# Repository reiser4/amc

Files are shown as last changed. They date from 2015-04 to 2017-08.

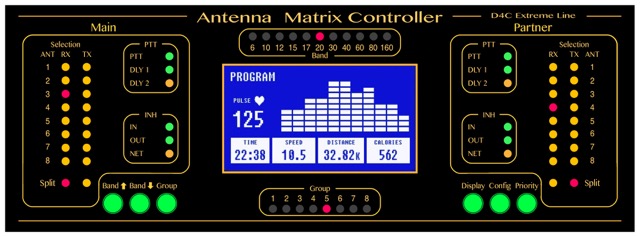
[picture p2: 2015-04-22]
webroot/front.jpg

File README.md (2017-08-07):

# amc

Software utilizzato su Windows:

 Python 3.5.0
 https://www.python.org/ftp/python/3.5.0/python-3.5.0-amd64-webinstall.exe

 PyQt5 5.5
 http://sourceforge.net/projects/pyqt/files/PyQt5/PyQt-5.5/PyQt5-5.5-gpl-Py3.4-Qt5.5.0-x64.exe

 py2exe 0.9.2.0
 https://pypi.python.org/packages/any/p/py2exe/py2exe-0.9.2.0.win-amd64.exe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

Per compilare per windows:

 python setup.py py2exe --includes sip

# funzionamento

il software AMC gira su beaglebone black. E` costituito da diversi componenti che interagiscono tra loro solamente tramite lettura e scrittura (atomica) di files in /tmp.

/tmp/band.txt
	contiene la banda in uso. puo` essere: 160, 80, 60, 40, 30, 20, 17, 15, 12, 10, 6

/tmp/relay.txt
	descrive i rele` attivi con la combinazione attuale di preset.
	esempio: 100000000000000000000000
	nella nostra implementazione usiamo i primi otto bits

/tmp/presetA.txt e /tmp/presetB.txt
	descrivono la combinazione da tastiera scelta dall'utente
	la pressione dei tasti provoca la variazione della combinazione
	esempio:
		TX: 01100000
		RX: 10010000

/tmp/presetTXTA.txt e /tmp/presetTXTB.txt
	contiene la lista testuale di preset attivi (per essere stampato sul display)
	senza spazi, separati da virgola, poi punto e virgola tra Rx e Tx
	esempio:
		Europa,Asia,America;Asia

/tmp/tx.txt
	contiene la lista di radio che stanno trasmettendo in quel momento
	esempio:
		A
		oppure
		B
		oppure 
		(file vuoto)

/root/amc/config.json
	contiene la configurazione con cui vengono determinate le varie combinazioni di relay da accendere.
	vedi file di esempio

# componenti software

MAIN:
	si occupa di prendere le decisioni riguardo i preset e relay da attivare.
	LEGGE: /root/amc/config.json /tmp/tx.txt /tmp/presetA.txt /tmp/presetB.txt /tmp/band.txt
	SCRIVE: /tmp/relay.txt /tmp/presetTXTA.txt /tmp/presetTXTB.txt

IOLOOP:
	ascolta il GPIO hardware per determinare la banda e la radio trasmittente.
	SCRIVE: /tmp/band.txt /tmp/tx.txt

DISPLAY:
	si occupa di mantenere il display aggiornato con lo stato attuale.
	LEGGE: /tmp/tx.txt /tmp/band.txt /tmp/presetTXTA.txt /tmp/presetTXTB.txt

KEYBOARD:
	rimane in ascolto di input da tastiera e fa i toggle dei bits dei preset
	LEGGE: /tmp/presetA.txt /tmp/presetB.txt
	SCRIVE: /tmp/presetA.txt /tmp/presetB.txt

SERIAL:
	svolge due funzioni: riporta periodicamente sulla seriale lo stato attuale per poter essere visualizzato sul pc,
	ed interagisce col pc per inviare e ricevere la configurazione.
	LEGGE: /tmp/presetA.txt /tmp/presetB.txt /tmp/tx.txt /tmp/band.txt /tmp/presetTXTA.txt /tmp/presetTXTB.txt /root/amc/config.json
	SCRIVE: /root/amc/config.json

RELAY:
	scrive su GPIO le uscite relay
	LEGGE: /tmp/relay.txt

CHECK:
	verifica che tutti i processi siano in esecuzione ed avvia eventuali processi fermi.

===================================

Requisiti software

# apt-get install git
# pip install Pillow

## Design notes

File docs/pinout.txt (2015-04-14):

PEDINATURA

P9_11 port B FTDI 232 tx
P9_12 LED shift register DATA OUT
P9_13 port B ftdi 232 rx
P9_14 led shift reg sck
P9_15 inh in A
P9_16 led shirf reg rck
P9_17 inh in B
P9_18 BCD A OUT

P9_22 BCD B OUT
P9_23 relay shift reg data out
P9_24 port A ftdi 232 tx
P9_25 relay shift reg sck
P9_26 port A ftdi 232 rx
P9_27 relay shift reg rck
P9_28 bcd c out
P9_29 inh out a
P9_30 bcd d out
P9_31 int out b
P9_33 icom voltage in
P9_41 button 3 in
P9_42 button 4 in

P8_07 ptt a out
P8_08 ptt a in
P8_09 ptt a out delay 1
P8_10 ptt b in
P8_11 ptt a out delay 2
P8_12 bcd a in
P8_13 ptt b out
P8_14 bcd b in
P8_15 ptt b out delay 1
P8_16 bcd c in
P8_17 ptt b out delay 2
P8_18 bcd d in
P8_19 button 1 in

P8_26 button 2 in

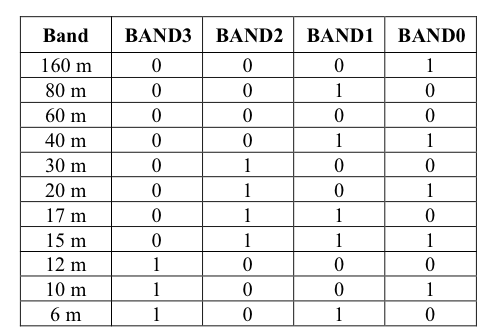
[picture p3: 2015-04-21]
docs/bcd.png

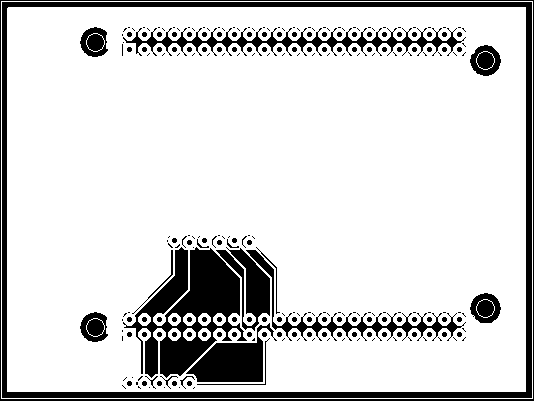
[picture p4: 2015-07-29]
eagle_file/Modulo0.png

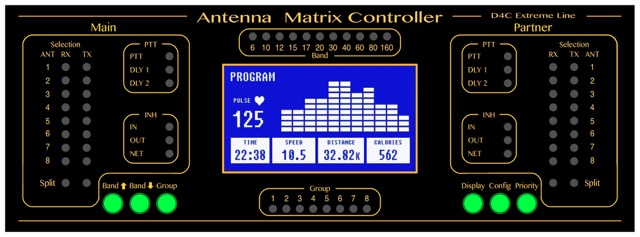
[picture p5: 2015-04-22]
webroot/front-off.jpg

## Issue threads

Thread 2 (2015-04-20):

lettura banda BCD

reiser4, 2015-04-20:
hardware: interfacciare gli ingressi BCD (5v) agli ingressi del micro (3.3v) tramite partitori resistivi

software: leggere i quattro piedini per determinare la banda

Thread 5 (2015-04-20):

gestione tastiere

reiser4, 2015-04-20:
software: creare un modulo che mantenga una memoria di tipo "toggle" dei tasti premuti.
gestire l'evento di pressione del tasto.
in secondo momento: gestire accensione e spegnimento dei led su barra x-keys

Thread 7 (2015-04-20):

driver i2c expander

reiser4, 2015-04-20:
creare un driver python per gestire ad alta velocita` l'i2c expander.
serve in sola scrittura, quindi chiamate tipo: setPin(5, HIGH)

Closed 2015-07-23.

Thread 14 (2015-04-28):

libreria grafica

reiser4, 2015-04-28:
funzione per disegnare una riga orizzontale o verticale
funzione per fare il testo a dimensione doppia

giulioribe, 2015-05-08:
Uso delle libreria Pillow: http://pillow.readthedocs.org/

Closed 2015-05-08.

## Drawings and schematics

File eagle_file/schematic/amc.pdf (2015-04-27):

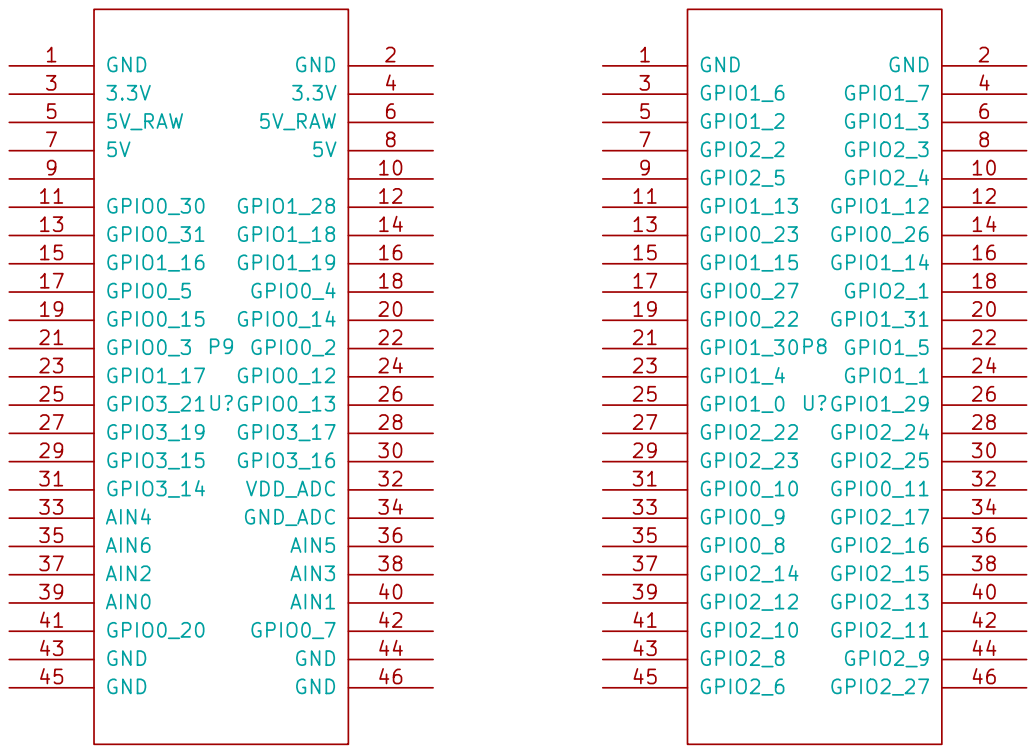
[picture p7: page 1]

Id: 1/1 Title: File: amc.sch Sheet: /

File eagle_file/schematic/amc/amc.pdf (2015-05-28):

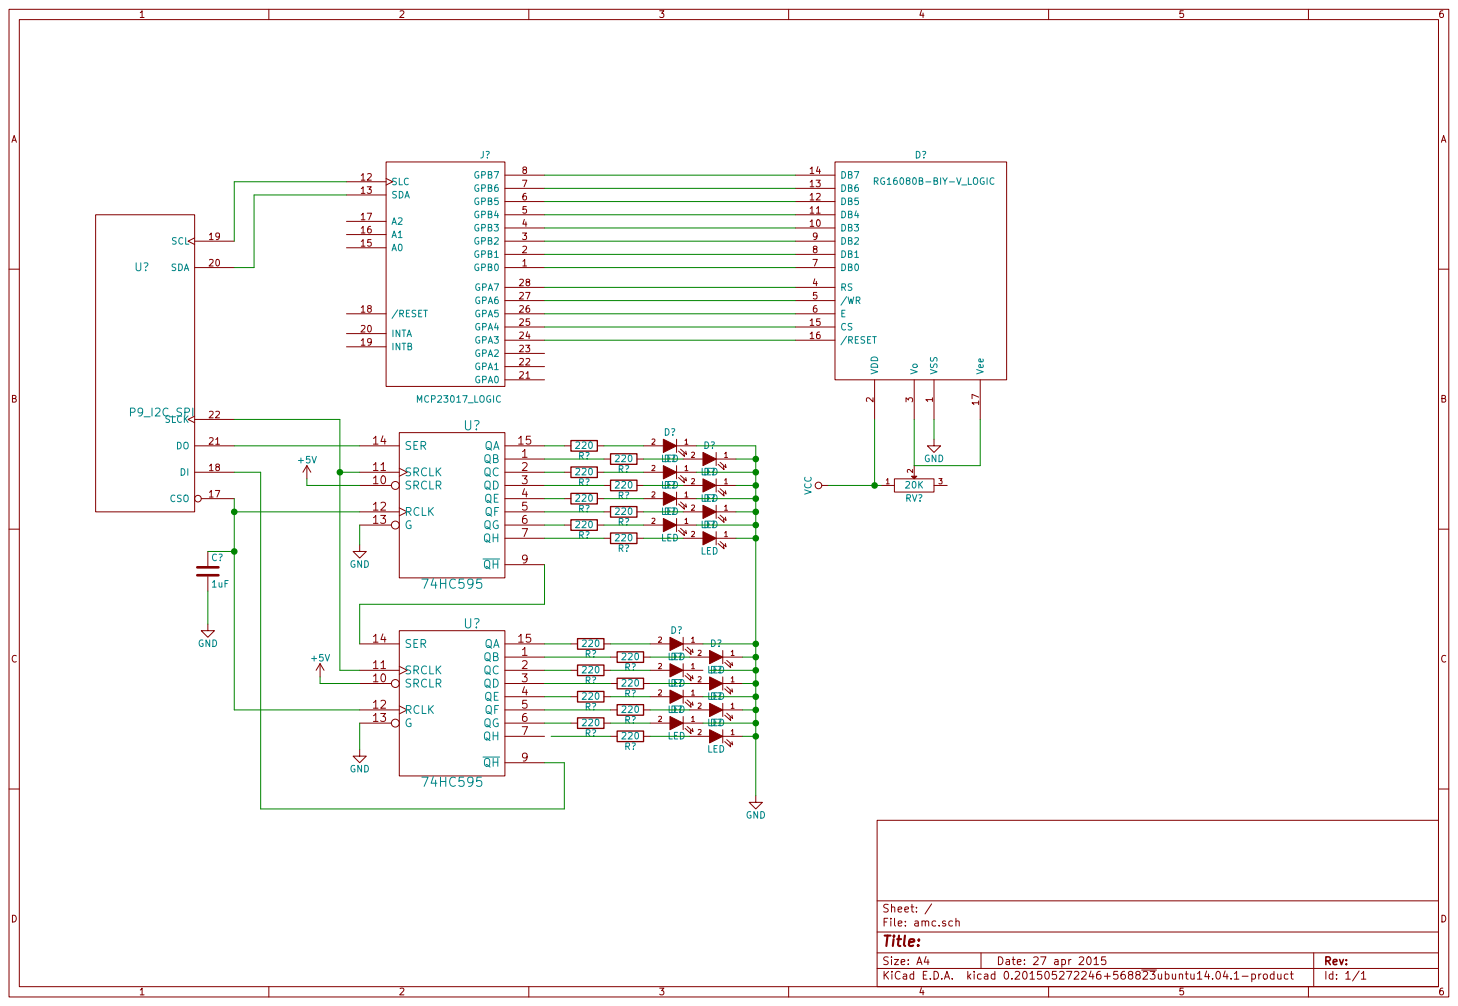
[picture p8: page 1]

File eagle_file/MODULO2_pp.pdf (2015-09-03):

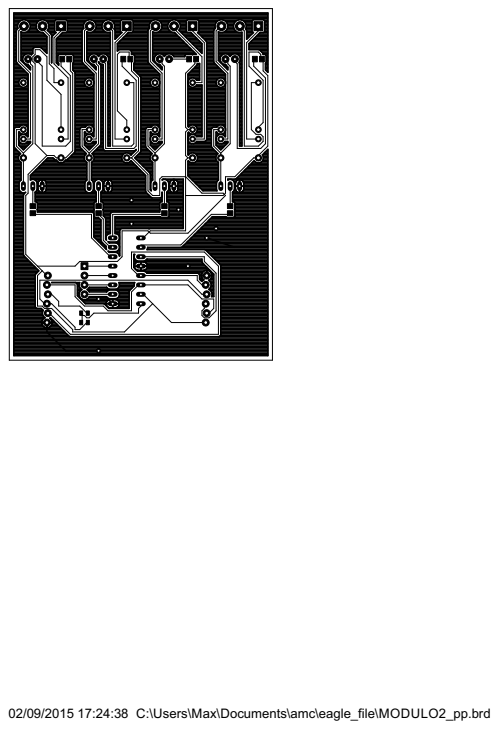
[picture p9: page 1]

02/09/2015 17:24:38 C:\Users\Max\Documents\amc\eagle_file\MODULO2_pp.brd

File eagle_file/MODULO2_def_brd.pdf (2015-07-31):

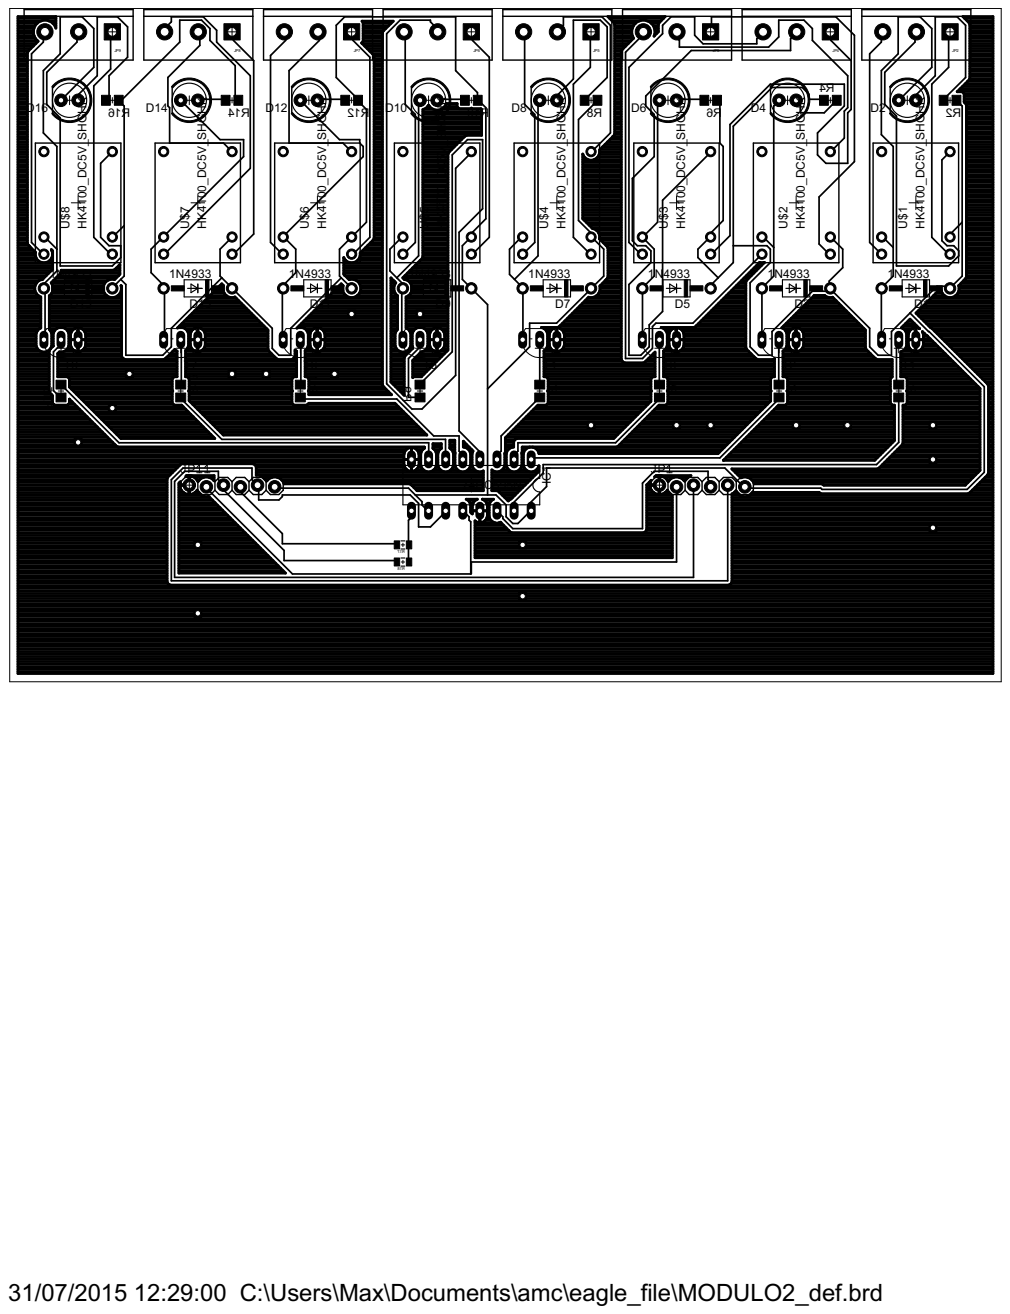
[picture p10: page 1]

31/07/2015 12:29:00 C:\Users\Max\Documents\amc\eagle_file\MODULO2_def.brd

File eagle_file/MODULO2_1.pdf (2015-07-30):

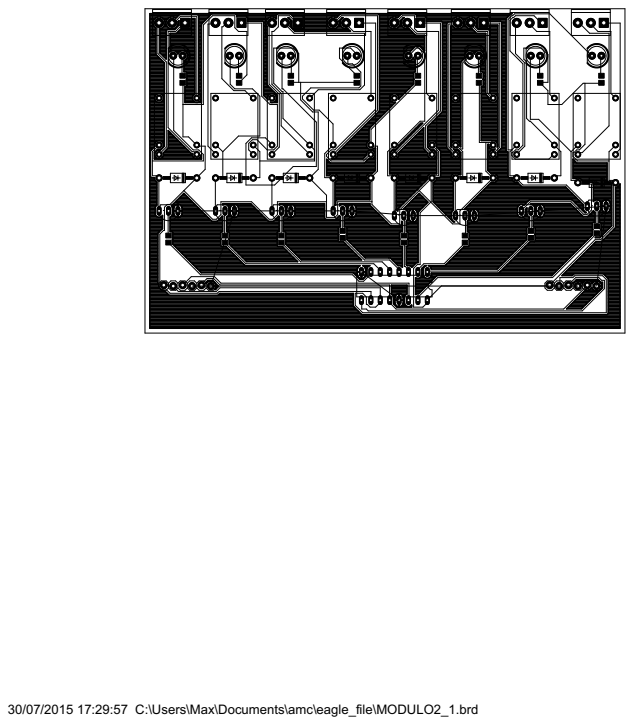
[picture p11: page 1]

30/07/2015 17:29:57 C:\Users\Max\Documents\amc\eagle_file\MODULO2_1.brd

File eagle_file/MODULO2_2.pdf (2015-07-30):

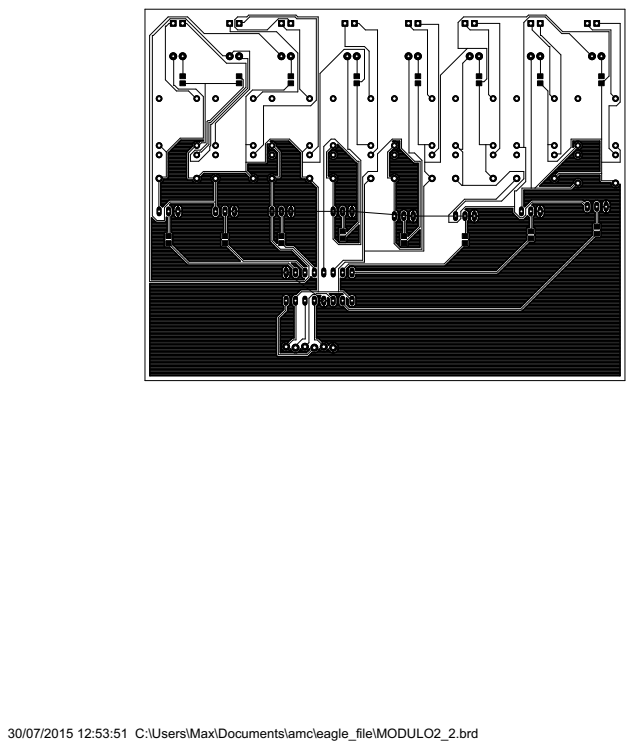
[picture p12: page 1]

30/07/2015 12:53:51 C:\Users\Max\Documents\amc\eagle_file\MODULO2_2.brd

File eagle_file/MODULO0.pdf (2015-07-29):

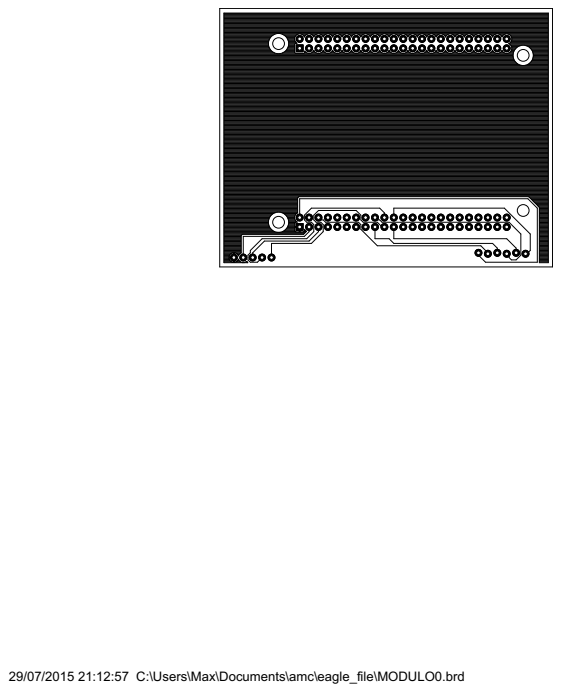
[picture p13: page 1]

29/07/2015 21:12:57 C:\Users\Max\Documents\amc\eagle_file\MODULO0.brd

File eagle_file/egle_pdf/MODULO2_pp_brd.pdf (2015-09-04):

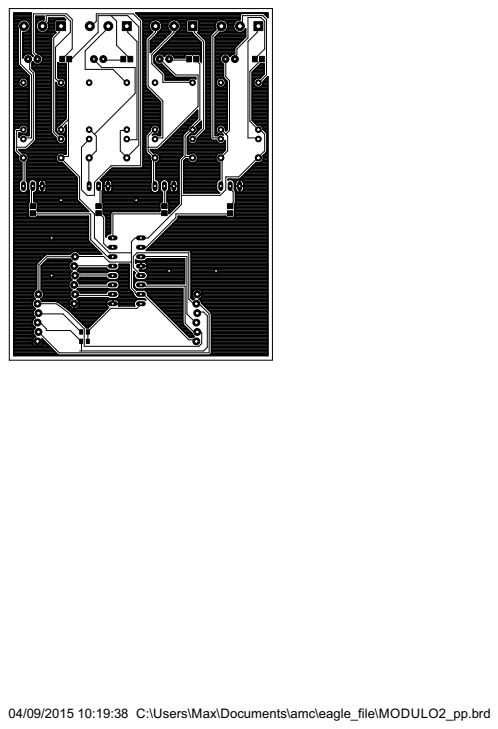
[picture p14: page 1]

04/09/2015 10:19:38 C:\Users\Max\Documents\amc\eagle_file\MODULO2_pp.brd

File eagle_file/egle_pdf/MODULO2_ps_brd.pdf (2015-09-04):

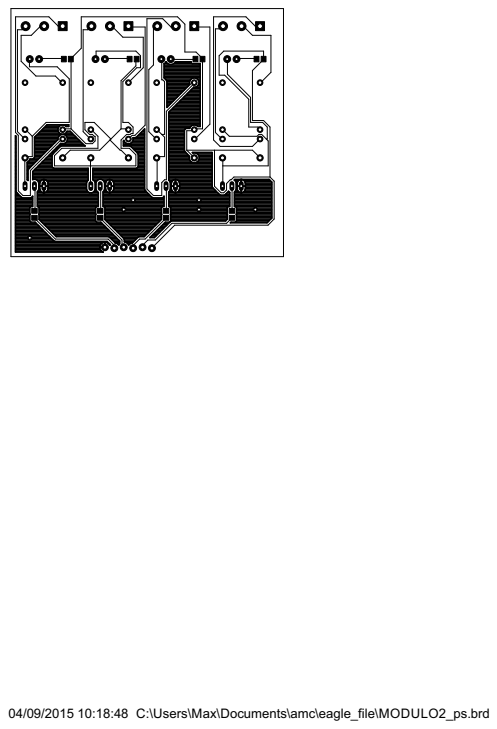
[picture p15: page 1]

04/09/2015 10:18:48 C:\Users\Max\Documents\amc\eagle_file\MODULO2_ps.brd

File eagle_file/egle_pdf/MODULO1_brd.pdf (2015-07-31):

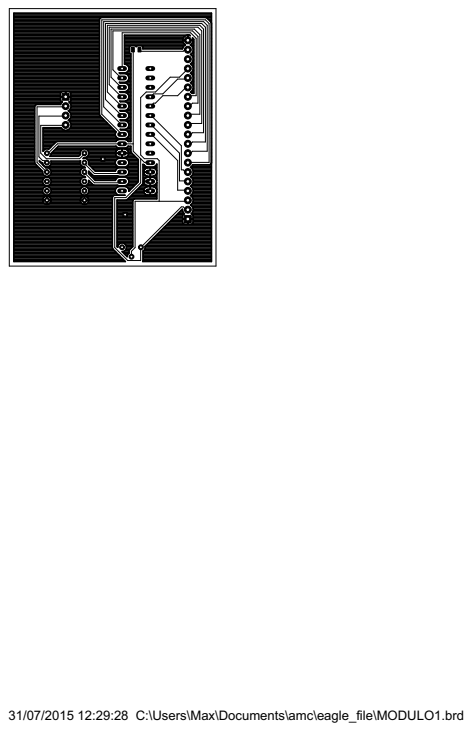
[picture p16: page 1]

31/07/2015 12:29:28 C:\Users\Max\Documents\amc\eagle_file\MODULO1.brd

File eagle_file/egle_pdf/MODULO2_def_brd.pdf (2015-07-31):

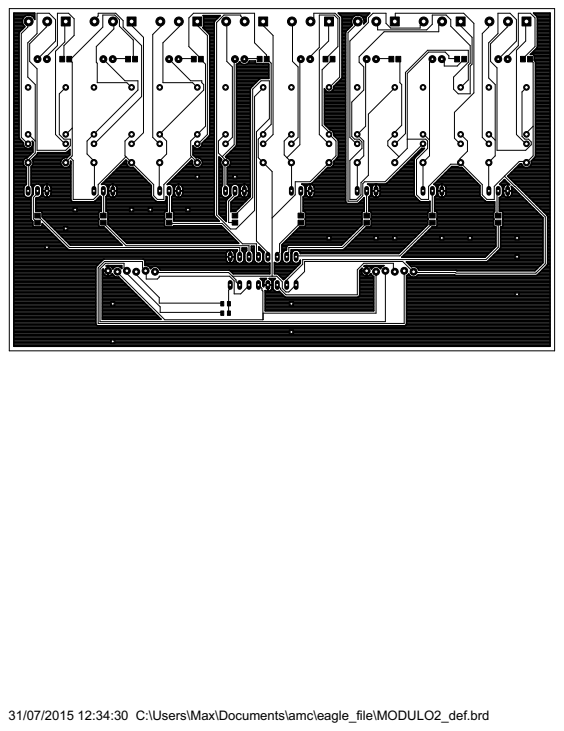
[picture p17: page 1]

31/07/2015 12:34:30 C:\Users\Max\Documents\amc\eagle_file\MODULO2_def.brd

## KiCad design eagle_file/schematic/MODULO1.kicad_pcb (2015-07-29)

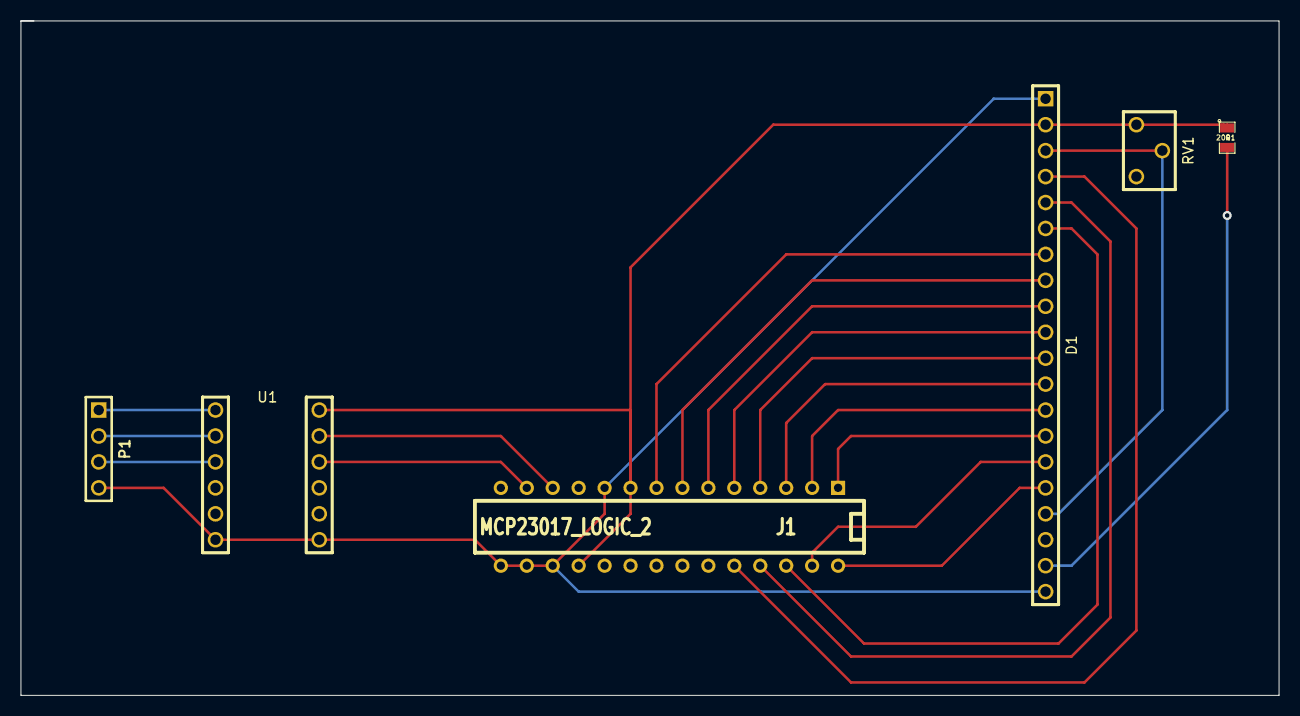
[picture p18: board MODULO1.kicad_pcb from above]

Board: 2 copper layers, 123.2 x 66.0 mm, 6 parts (0 on the bottom side), 22 nets.

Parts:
D1: RG16080B-BIY-V_LOGIC_2; ZZPIN20
J1: MCP23017_LOGIC_2; DIP-28__300
P1: CONN_4; PIN_ARRAY_4x1
R1: 200; SM0805
RV1: POT; ZZTRIMMER
U1: L_CONVERTER

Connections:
/SCL: P1.2, U1.2
/SDA: P1.3, U1.3
GND: D1.1, D1.20, J1.10, J1.15, J1.16, J1.17, P1.4, U1.6, U1.7
unnamed: J1.13, U1.10
unnamed: D1.12, J1.3
unnamed: D1.13, J1.2
unnamed: D1.11, J1.4
unnamed: D1.10, J1.5
unnamed: D1.9, J1.6
unnamed: D1.8, J1.7
unnamed: D1.7, J1.8
unnamed: D1.5, J1.25
unnamed: D1.2, J1.9, J1.18, R1.1, RV1.1, U1.12
unnamed: D1.4, J1.24
unnamed: D1.6, J1.26
unnamed: D1.15, J1.27
unnamed: D1.16, J1.28
unnamed: D1.3, D1.17, RV1.2
unnamed: J1.12, U1.11
unnamed: D1.19, R1.2
unnamed: D1.14, J1.1
VCC: P1.1, U1.1

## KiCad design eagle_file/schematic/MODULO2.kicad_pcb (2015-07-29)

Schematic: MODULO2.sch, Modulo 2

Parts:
D1, D2, D3, D4, D5, D6, D7, D8: LED
P1: CONN_6
R1, R2, R3, R4, R5, R6, R7, R8: R
U1: 74HC595

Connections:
/SCLK: P1.2, U1.11 (SRCLK)
GND: D1.2 (A), D2.2 (A), D3.2 (A), D4.2 (A), D5.2 (A), D6.2 (A), D7.2 (A), D8.2 (A), P1.6, U1.8 (GND), U1.13 (G)
unnamed: R4.1, U1.6 (QG)
unnamed: D7.1 (K), R7.2
unnamed: R7.1, U1.5 (QF)
unnamed: D3.1 (K), R3.2
unnamed: R3.1, U1.4 (QE)
unnamed: D4.1 (K), R4.2
unnamed: D6.1 (K), R6.2
unnamed: R6.1, U1.3 (QD)
unnamed: D2.1 (K), R2.2
unnamed: R2.1, U1.2 (QC)
unnamed: D5.1 (K), R5.2
unnamed: R5.1, U1.1 (QB)
unnamed: D8.1 (K), R8.2
unnamed: R8.1, U1.7 (QH)
unnamed: R1.1, U1.15 (QA)
unnamed: P1.3, U1.14 (SER)
unnamed: P1.5, U1.12 (RCLK)
unnamed: D1.1 (K), R1.2
unnamed: P1.4, U1.9 (~QH)
VCC: P1.1, U1.10 (SRCLR), U1.16 (VCC)

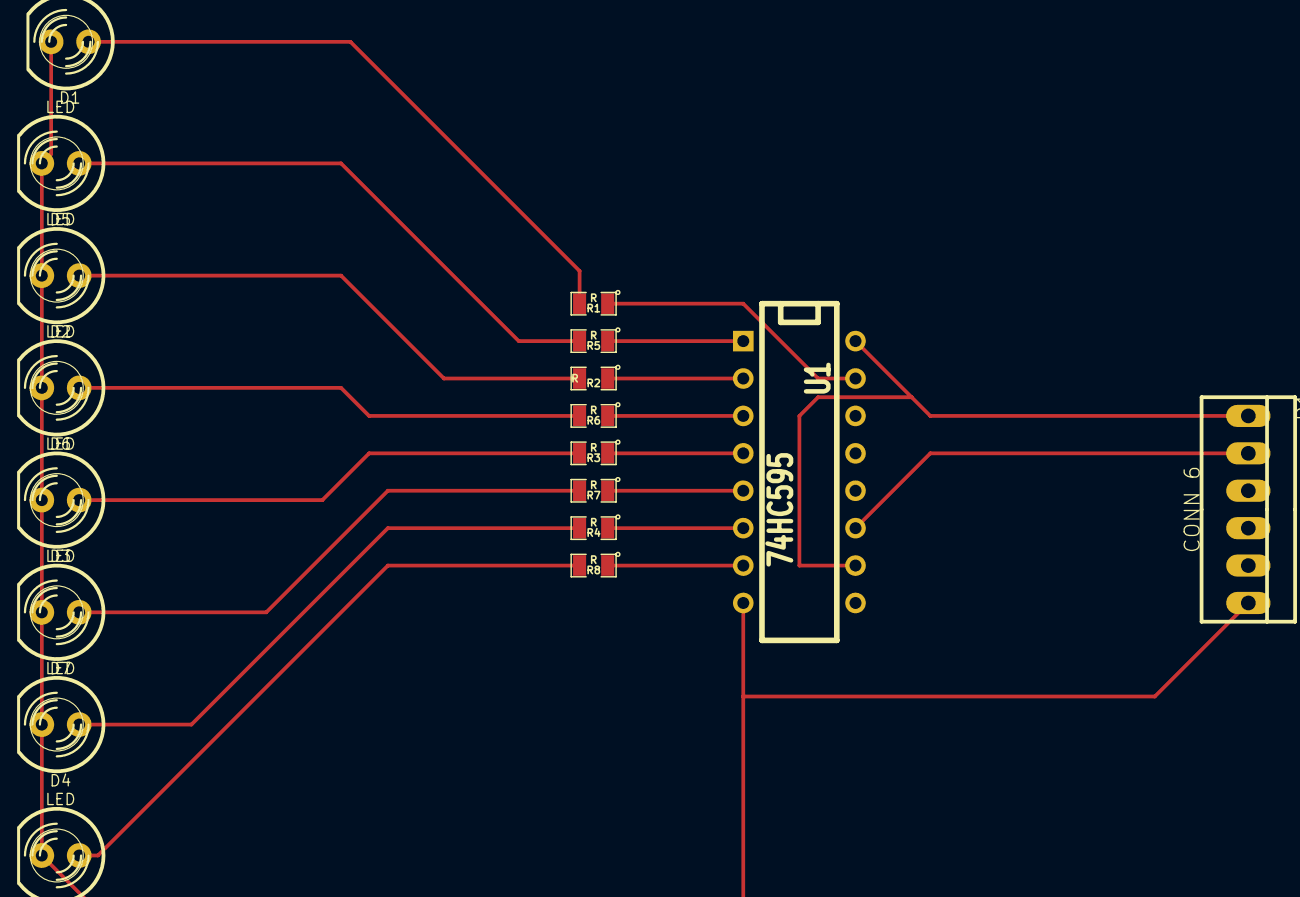
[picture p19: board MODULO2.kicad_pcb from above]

Board: 2 copper layers, 18 parts (0 on the bottom side), 22 nets.

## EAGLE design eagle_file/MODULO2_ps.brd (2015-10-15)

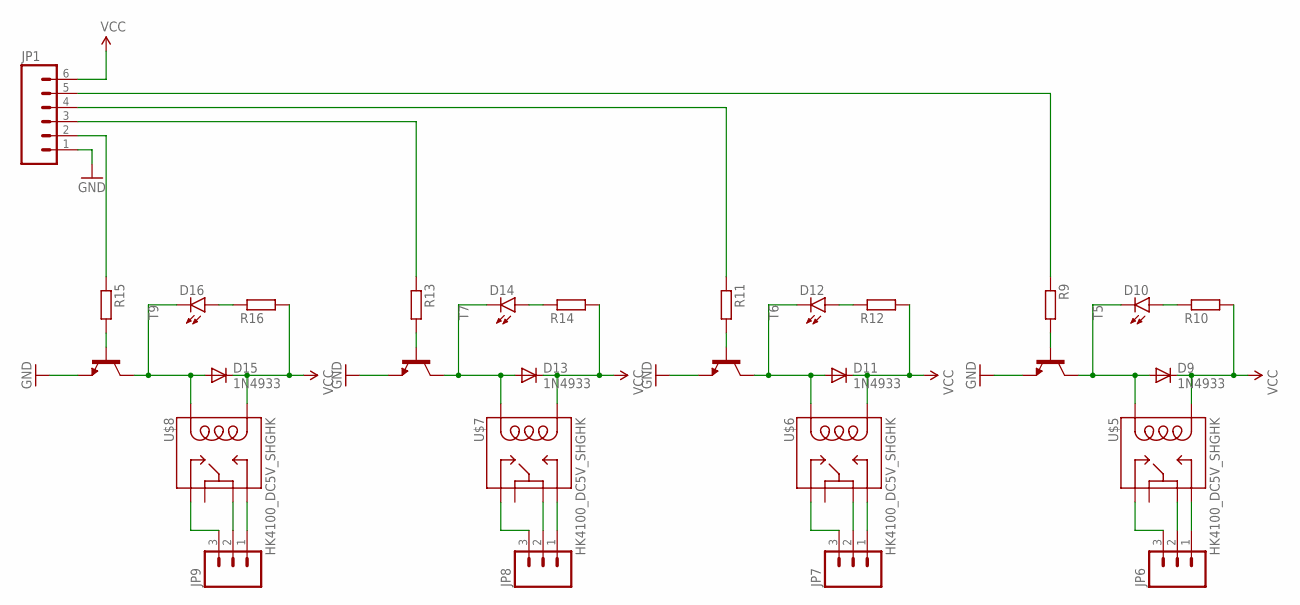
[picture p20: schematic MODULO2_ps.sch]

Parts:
D9, D11, D13, D15: 1N4933; DO41-10
D10, D12, D14, D16: LED5MM
JP1: M06SILK_FEMALE_PTH; 1X06
JP6, JP7, JP8, JP9: M03-SCREW-5MM; SCREWTERMINAL-5MM-3
R9, R10, R11, R12, R13, R14, R15, R16: R-EU_R0805; R0805
T5, T6, T7, T9: -NPN-TO92-EBC; TO92-EBC
U$5, U$6, U$7, U$8: HK4100_DC5V_SHGHK; HK4100

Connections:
GND: JP1.1, T5.E, T6.E, T7.E, T9.E
unnamed: D9.A, D10.K (C), T5.C, U$5.6 (2)
unnamed: D10.A, R10.1
unnamed: R9.2, T5.B
unnamed: D11.A, D12.K (C), T6.C, U$6.6 (2)
unnamed: D12.A, R12.1
unnamed: R11.2, T6.B
unnamed: D13.A, D14.K (C), T7.C, U$7.6 (2)
unnamed: D14.A, R14.1
unnamed: R13.2, T7.B
unnamed: D15.A, D16.K (C), T9.C, U$8.6 (2)
unnamed: D16.A, R16.1
unnamed: R15.2, T9.B
unnamed: JP1.4, R11.1
unnamed: JP1.5, R9.1
unnamed: JP1.3, R13.1
unnamed: JP1.2, R15.1
unnamed: JP6.1, U$5.8 (10)
unnamed: JP6.2, U$5.14 (6)
unnamed: JP6.3, U$5.7 (1)
unnamed: JP7.1, U$6.8 (10)
unnamed: JP7.2, U$6.14 (6)
unnamed: JP7.3, U$6.7 (1)
unnamed: JP8.1, U$7.8 (10)
unnamed: JP8.2, U$7.14 (6)
unnamed: JP8.3, U$7.7 (1)
unnamed: JP9.1, U$8.8 (10)
unnamed: JP9.2, U$8.14 (6)
unnamed: JP9.3, U$8.7 (1)
VCC: D9.C, D11.C, D13.C, D15.C, JP1.6, R10.2, R12.2, R14.2, R16.2, U$5.9, U$6.9, U$7.9, U$8.9

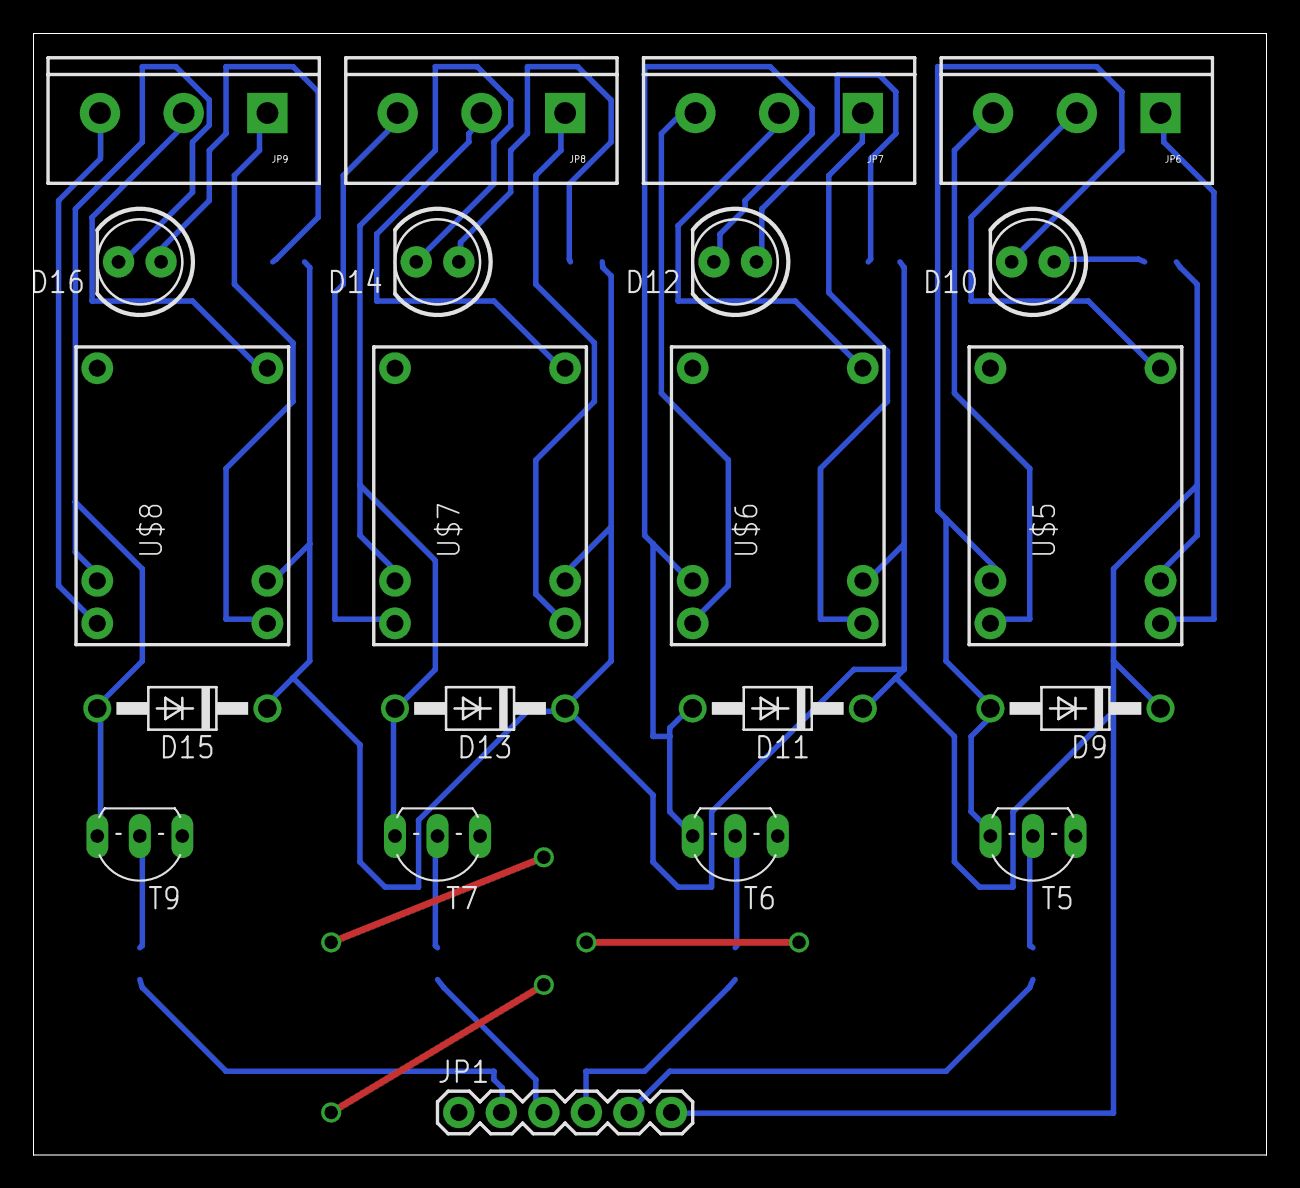
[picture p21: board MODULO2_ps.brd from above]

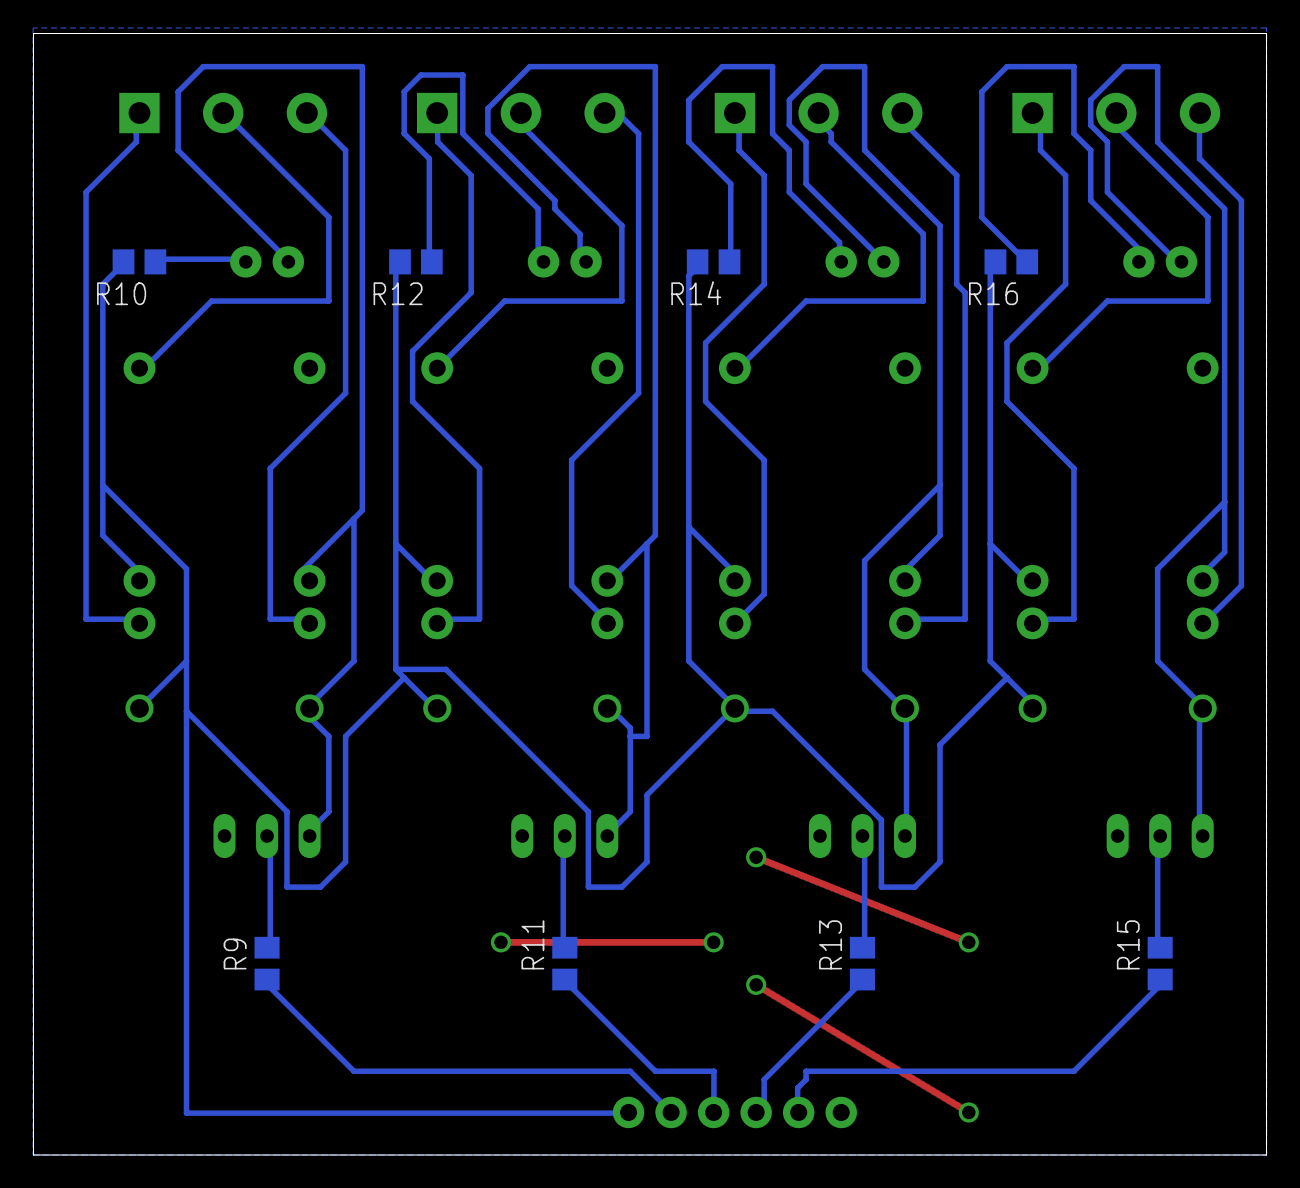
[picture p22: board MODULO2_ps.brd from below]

Board: 2 copper layers, 73.6 x 67.0 mm, 29 parts (8 on the bottom side), 30 nets.

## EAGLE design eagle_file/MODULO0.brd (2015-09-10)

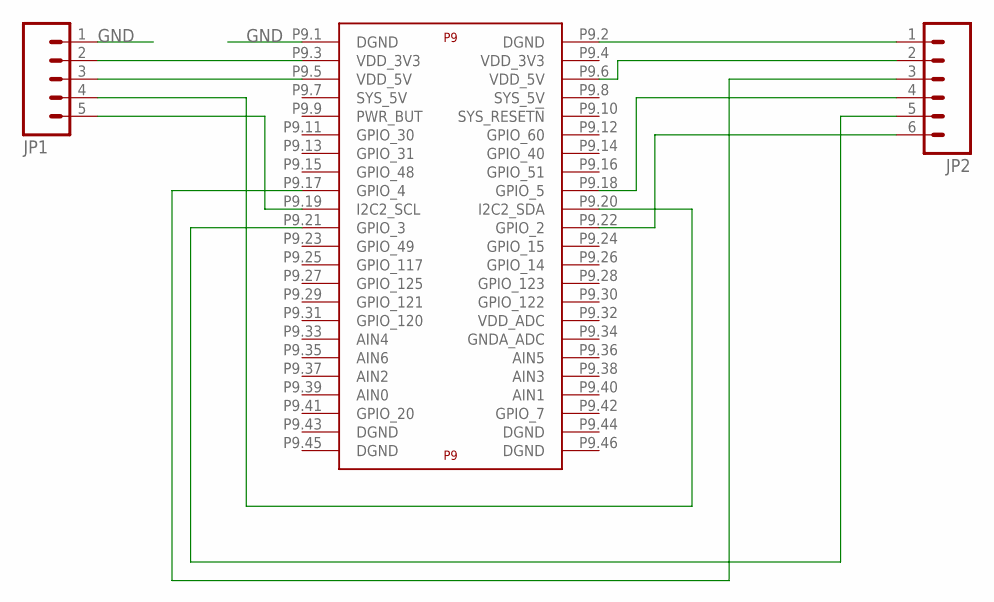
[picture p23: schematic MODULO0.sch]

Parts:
JP1: M05PTH; 1X05
JP2: M06SILK_FEMALE_PTH; 1X06
U$1: BEAGLE_BONE_BLACK_CAPE

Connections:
GND: JP1.1, U$1.P9.1 (DGND)
unnamed: JP1.2, U$1.P9.3 (VDD_3V3)
unnamed: JP1.3, U$1.P9.5 (VDD_5V)
unnamed: JP1.5, U$1.P9.19 (I2C2_SCL)
unnamed: JP1.4, U$1.P9.20 (I2C2_SDA)
unnamed: JP2.1, U$1.P9.2 (DGND)
unnamed: JP2.2, U$1.P9.6 (VDD_5V)
unnamed: JP2.3, U$1.P9.17 (GPIO_4)
unnamed: JP2.4, U$1.P9.18 (GPIO_5)
unnamed: JP2.6, U$1.P9.22 (GPIO_2)
unnamed: JP2.5, U$1.P9.21 (GPIO_3)

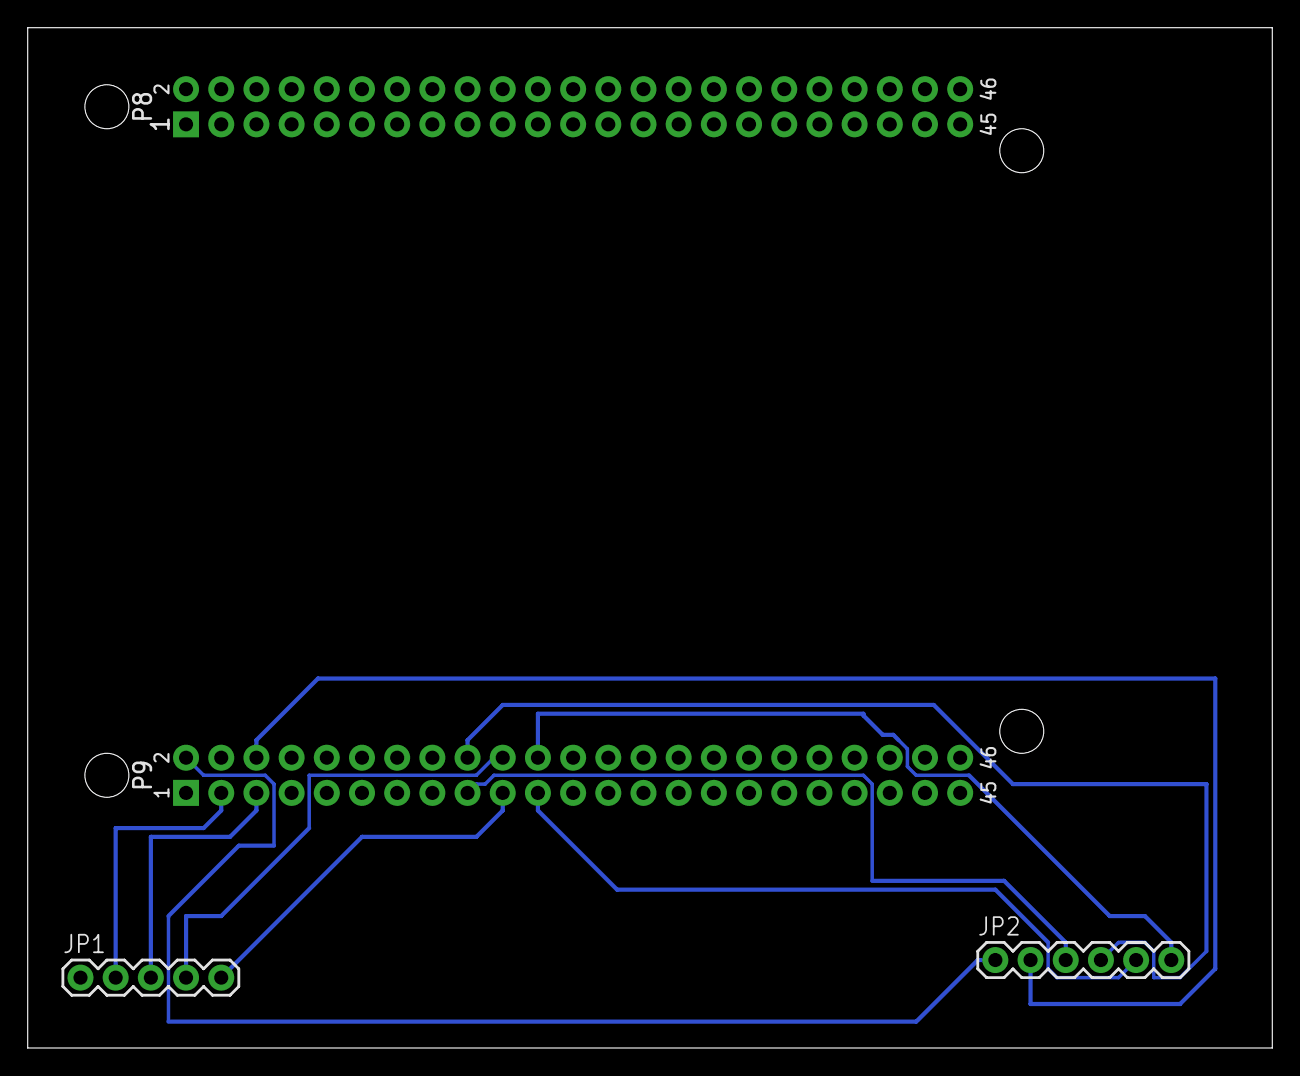
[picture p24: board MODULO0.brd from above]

Board: 2 copper layers, 89.8 x 73.7 mm, 3 parts (0 on the bottom side), 11 nets.

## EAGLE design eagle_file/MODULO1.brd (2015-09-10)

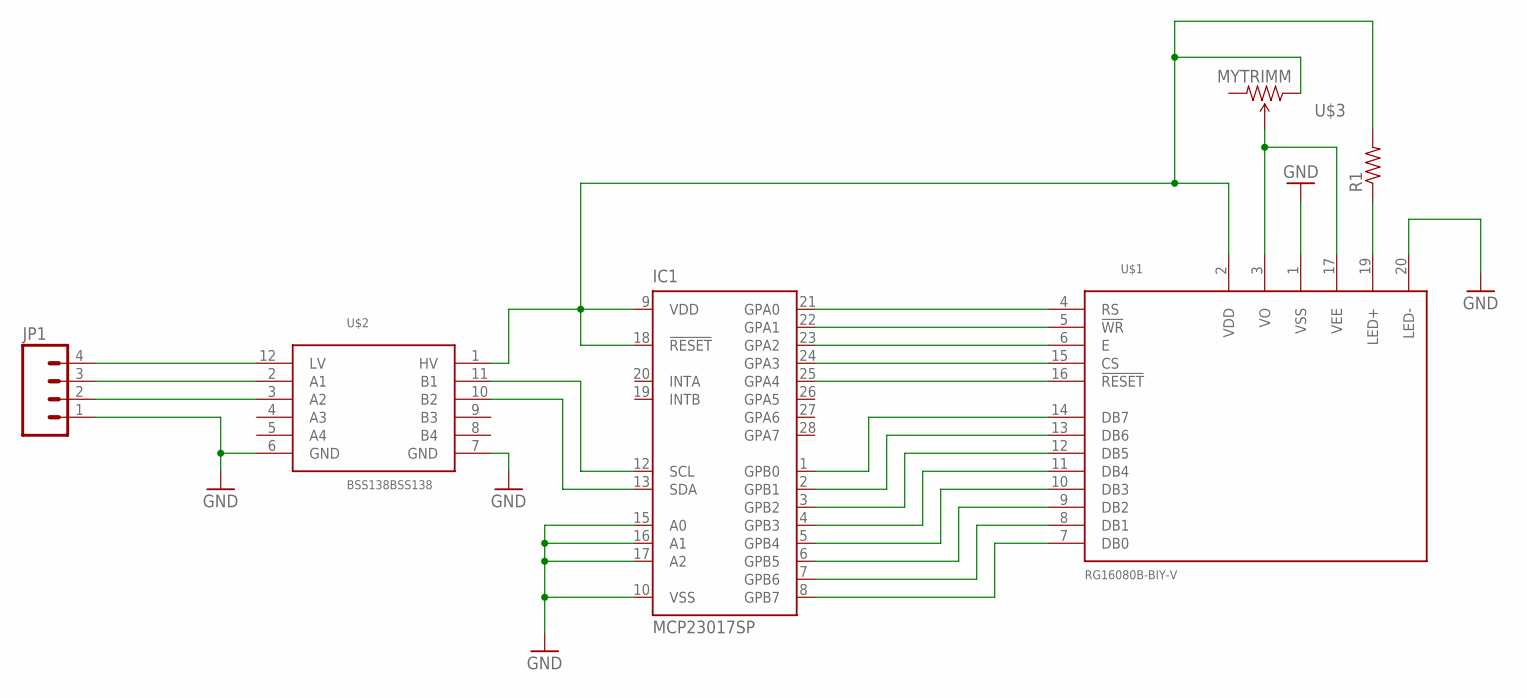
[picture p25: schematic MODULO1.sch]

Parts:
IC1: MCP23017SP; DIL28-3
JP1: M04PTH; 1X04
R1: RESISTOR0805-RES; 0805
U$1: RG16080B-BIY-V; 1X20
U$2: BSS138BSS138; BSS138
U$3: MYTRIMM

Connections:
GND: IC1.10 (VSS), IC1.15 (A0), IC1.16 (A1), IC1.17 (A2), JP1.1, U$1.1 (VSS), U$1.20 (LED-), U$2.6 (GND), U$2.7 (GND)
unnamed: IC1.21 (GPA0), U$1.4 (RS)
unnamed: IC1.22 (GPA1), U$1.5 (!WR)
unnamed: IC1.23 (GPA2), U$1.6 (E)
unnamed: IC1.24 (GPA3), U$1.15 (CS)
unnamed: IC1.25 (GPA4), U$1.16 (!RESET)
unnamed: IC1.1 (GPB0), U$1.14 (DB7)
unnamed: IC1.2 (GPB1), U$1.13 (DB6)
unnamed: IC1.3 (GPB2), U$1.12 (DB5)
unnamed: IC1.4 (GPB3), U$1.11 (DB4)
unnamed: IC1.5 (GPB4), U$1.10 (DB3)
unnamed: IC1.6 (GPB5), U$1.9 (DB2)
unnamed: IC1.7 (GPB6), U$1.8 (DB1)
unnamed: IC1.8 (GPB7), U$1.7 (DB0)
unnamed: IC1.9 (VDD), IC1.18 (!RESET), R1.2, U$1.2 (VDD), U$2.1 (HV), U$3.1 (CCW)
unnamed: IC1.12 (SCL), U$2.11 (B1)
unnamed: IC1.13 (SDA), U$2.10 (B2)
unnamed: JP1.4, U$2.12 (LV)
unnamed: JP1.3, U$2.2 (A1)
unnamed: JP1.2, U$2.3 (A2)
unnamed: U$1.3 (VO), U$1.17 (VEE), U$3.2 (WIPER)
unnamed: R1.1, U$1.19 (LED+)

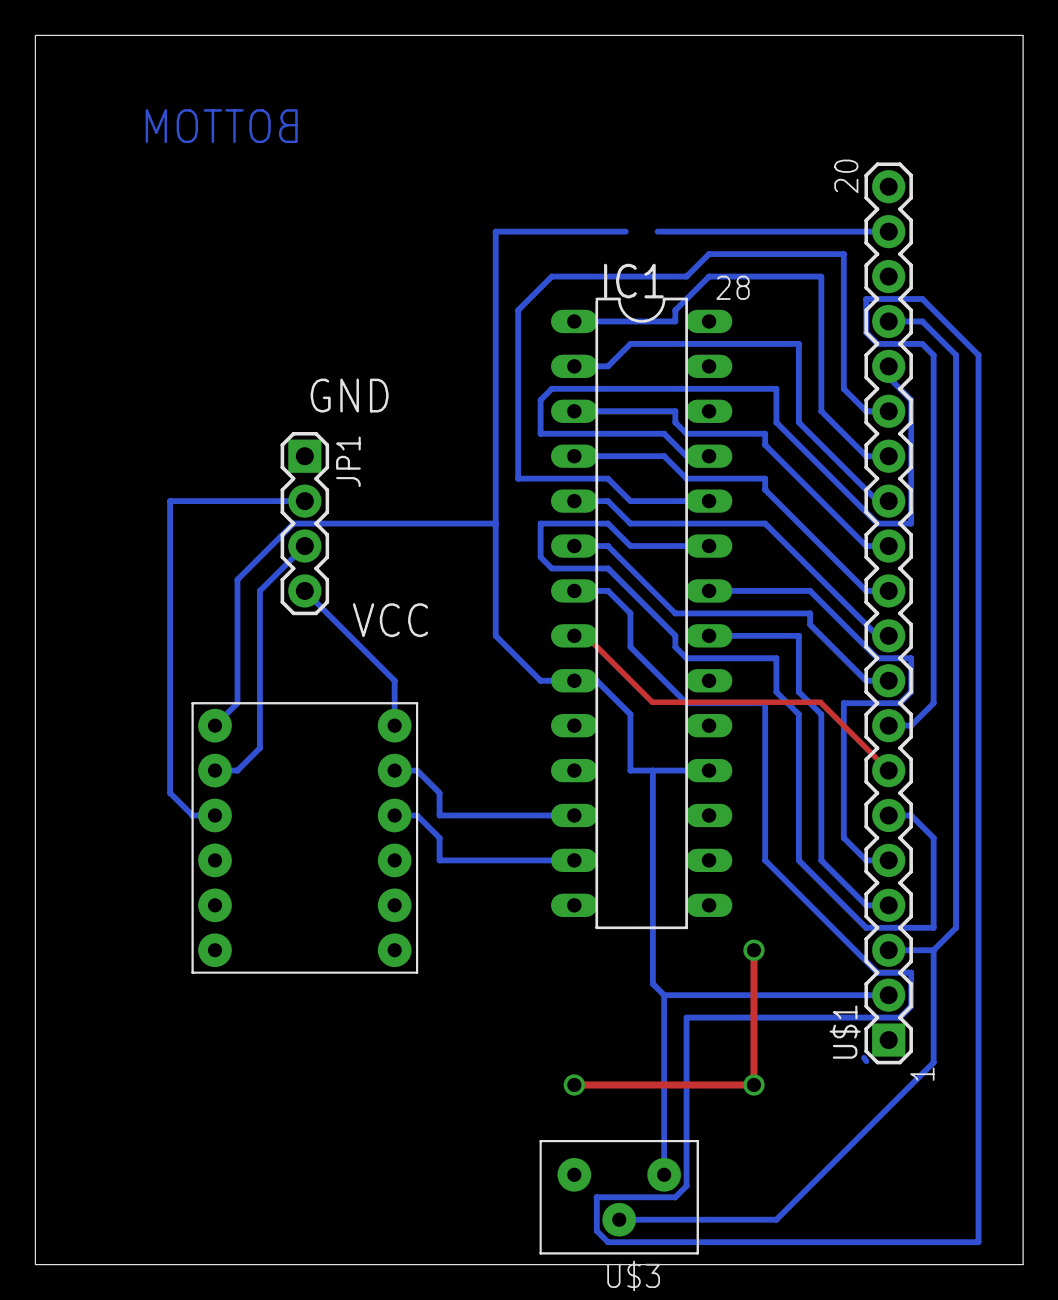
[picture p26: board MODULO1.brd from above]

Board: 2 copper layers, 55.9 x 69.5 mm, 6 parts (1 on the bottom side), 22 nets.

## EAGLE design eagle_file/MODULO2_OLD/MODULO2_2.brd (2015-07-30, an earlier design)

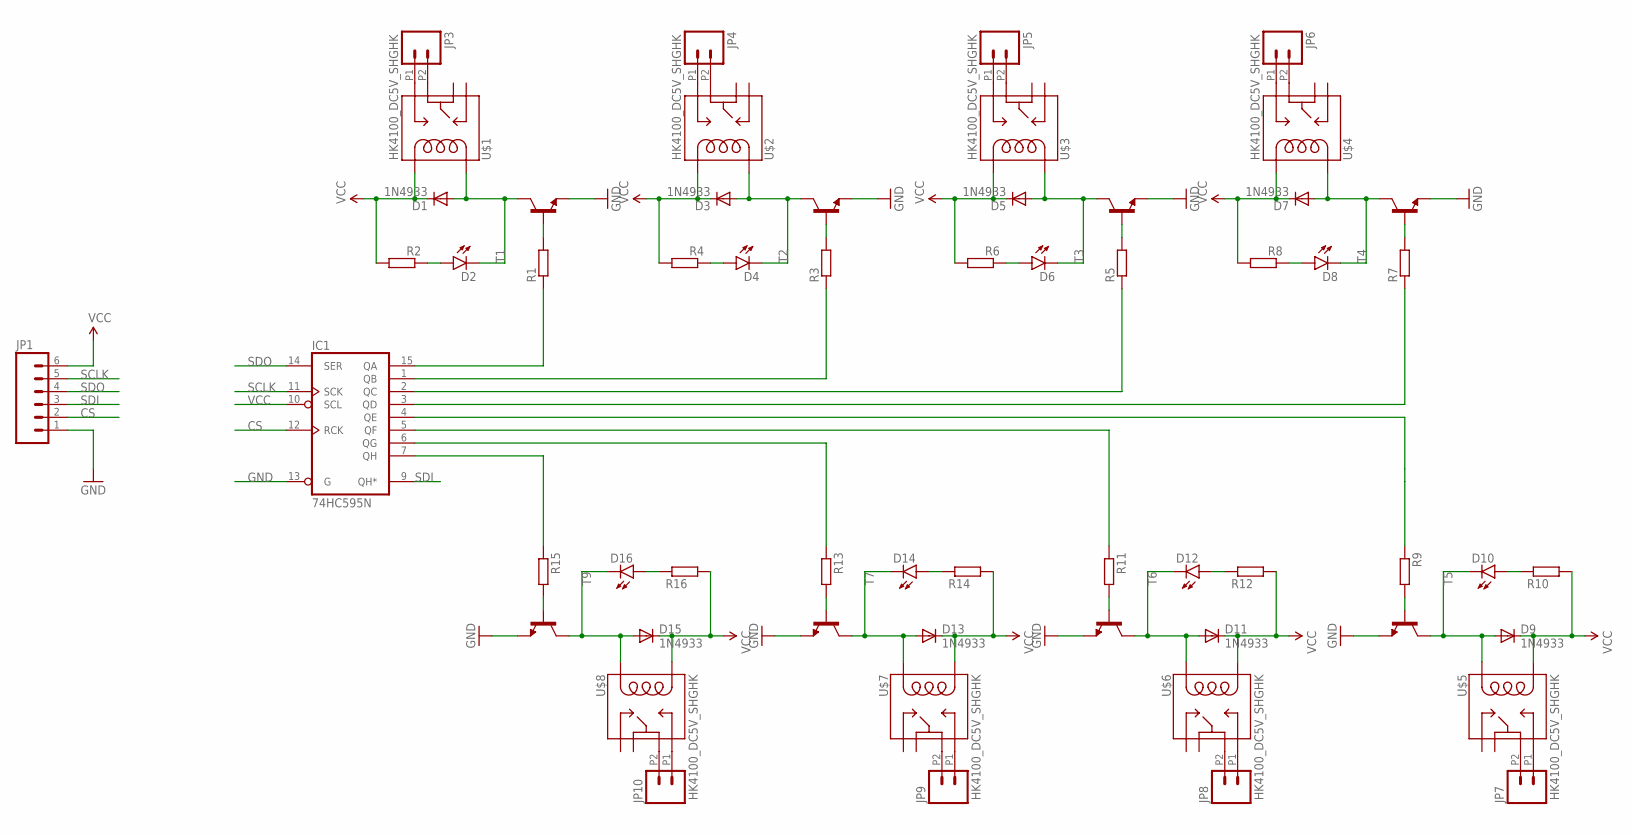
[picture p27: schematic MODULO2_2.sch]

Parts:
D1, D3, D5, D7, D9, D11, D13, D15: 1N4933; DO41-10
D2, D4, D6, D8, D10, D12, D14, D16: LED5MM
IC1: 74HC595N; DIL16
JP1: M06LOCK; 1X06_LOCK
JP3, JP4, JP5, JP6, JP7, JP8, JP9, JP10: M022.54MM_SCREWTERM; 1X02_2.54_SCREWTERM
R1, R2, R3, R4, R5, R6, R7, R8, R9, R10, R11, R12, R13, R14, R15, R16: R-EU_R0805; R0805
T1, T2, T3, T4, T5, T6, T7, T9: -NPN-TO92-EBC; TO92-EBC
U$1, U$2, U$3, U$4, U$5, U$6, U$7, U$8: HK4100_DC5V_SHGHK; HK4100

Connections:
CS: IC1.12 (RCK), JP1.2
GND: IC1.8 (GND), IC1.13 (G), JP1.1, T1.E, T2.E, T3.E, T4.E, T5.E, T6.E, T7.E, T9.E
unnamed: IC1.15 (QA), R1.1
unnamed: IC1.1 (QB), R3.1
unnamed: D1.A, D2.K (C), T1.C, U$1.6 (2)
unnamed: D2.A, R2.1
unnamed: R1.2, T1.B
unnamed: D3.A, D4.K (C), T2.C, U$2.6 (2)
unnamed: D5.A, D6.K (C), T3.C, U$3.6 (2)
unnamed: D6.A, R6.1
unnamed: R5.2, T3.B
unnamed: D7.A, D8.K (C), T4.C, U$4.6 (2)
unnamed: D8.A, R8.1
unnamed: R7.2, T4.B
unnamed: IC1.3 (QD), R7.1
unnamed: D4.A, R4.1
unnamed: R3.2, T2.B
unnamed: IC1.2 (QC), R5.1
unnamed: D9.A, D10.K (C), T5.C, U$5.6 (2)
unnamed: D10.A, R10.1
unnamed: R9.2, T5.B
unnamed: D11.A, D12.K (C), T6.C, U$6.6 (2)
unnamed: D12.A, R12.1
unnamed: R11.2, T6.B
unnamed: D13.A, D14.K (C), T7.C, U$7.6 (2)
unnamed: D14.A, R14.1
unnamed: R13.2, T7.B
unnamed: D15.A, D16.K (C), T9.C, U$8.6 (2)
unnamed: D16.A, R16.1
unnamed: R15.2, T9.B
unnamed: IC1.5 (QF), R11.1
unnamed: IC1.4 (QE), R9.1
unnamed: IC1.6 (QG), R13.1
unnamed: IC1.7 (QH), R15.1
unnamed: JP3.P1 (1), U$1.8 (10)
unnamed: JP3.P2 (2), U$1.14 (6)
unnamed: JP4.P1 (1), U$2.8 (10)
unnamed: JP4.P2 (2), U$2.14 (6)
unnamed: JP5.P1 (1), U$3.8 (10)
unnamed: JP5.P2 (2), U$3.14 (6)
unnamed: JP6.P1 (1), U$4.8 (10)
unnamed: JP6.P2 (2), U$4.14 (6)
unnamed: JP7.P1 (1), U$5.8 (10)
unnamed: JP7.P2 (2), U$5.14 (6)
unnamed: JP8.P1 (1), U$6.8 (10)
unnamed: JP8.P2 (2), U$6.14 (6)
unnamed: JP9.P1 (1), U$7.8 (10)
unnamed: JP9.P2 (2), U$7.14 (6)
unnamed: JP10.P1 (1), U$8.8 (10)
unnamed: JP10.P2 (2), U$8.14 (6)
SCLK: IC1.11 (SCK), JP1.5
SDI: IC1.9 (QH*), JP1.3
SDO: IC1.14 (SER), JP1.4
VCC: D1.C, D3.C, D5.C, D7.C, D9.C, D11.C, D13.C, D15.C, IC1.10 (SCL), IC1.16 (VCC), JP1.6, R2.2, R4.2, R6.2, R8.2, R10.2, R12.2, R14.2, R16.2, U$1.9, U$2.9, U$3.9, U$4.9, U$5.9, U$6.9, U$7.9, U$8.9

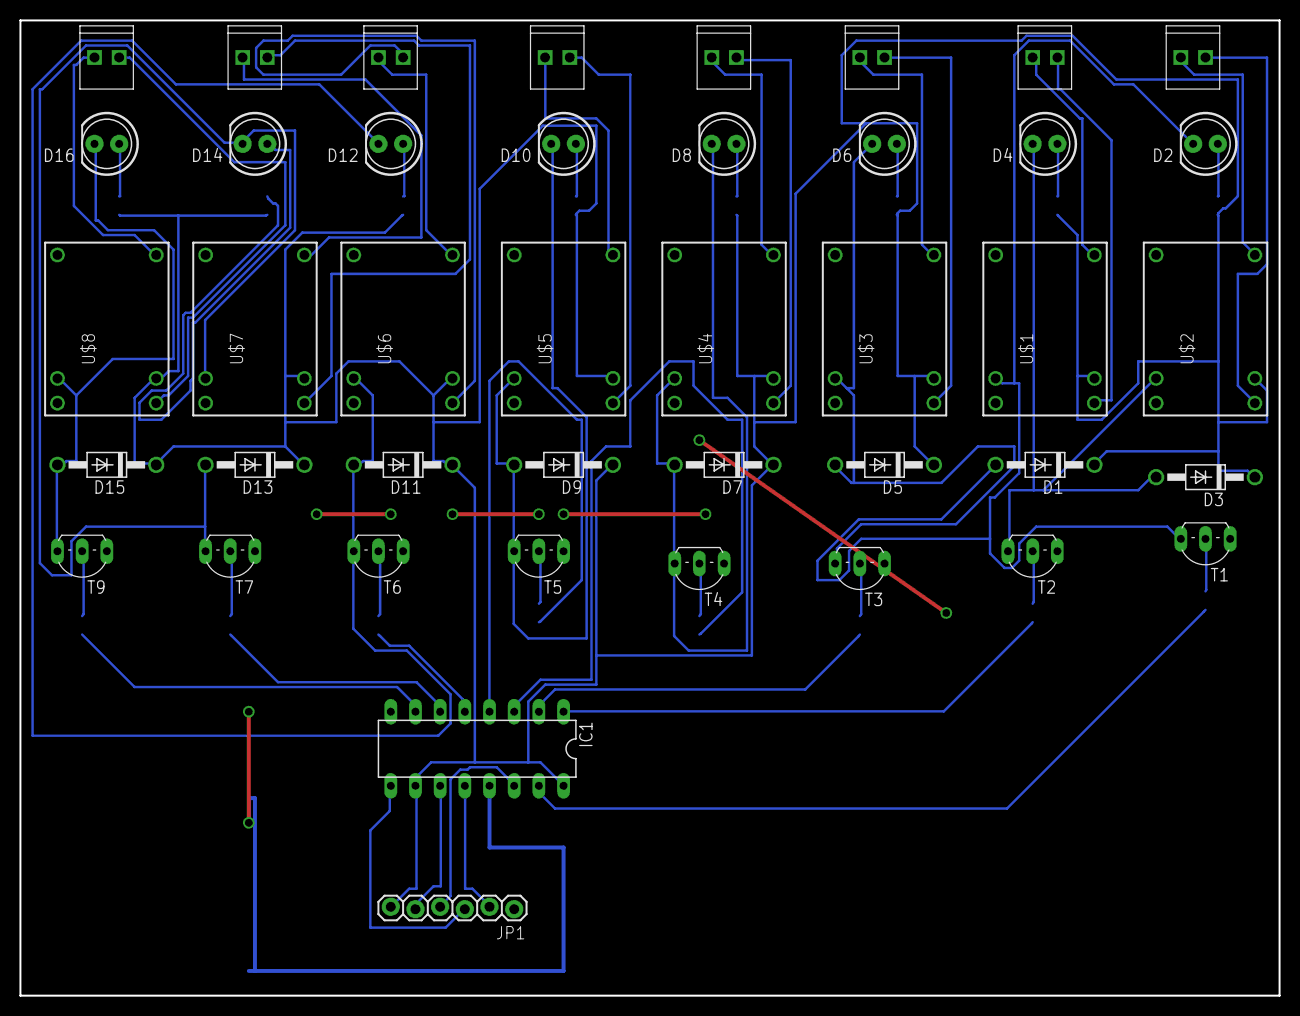
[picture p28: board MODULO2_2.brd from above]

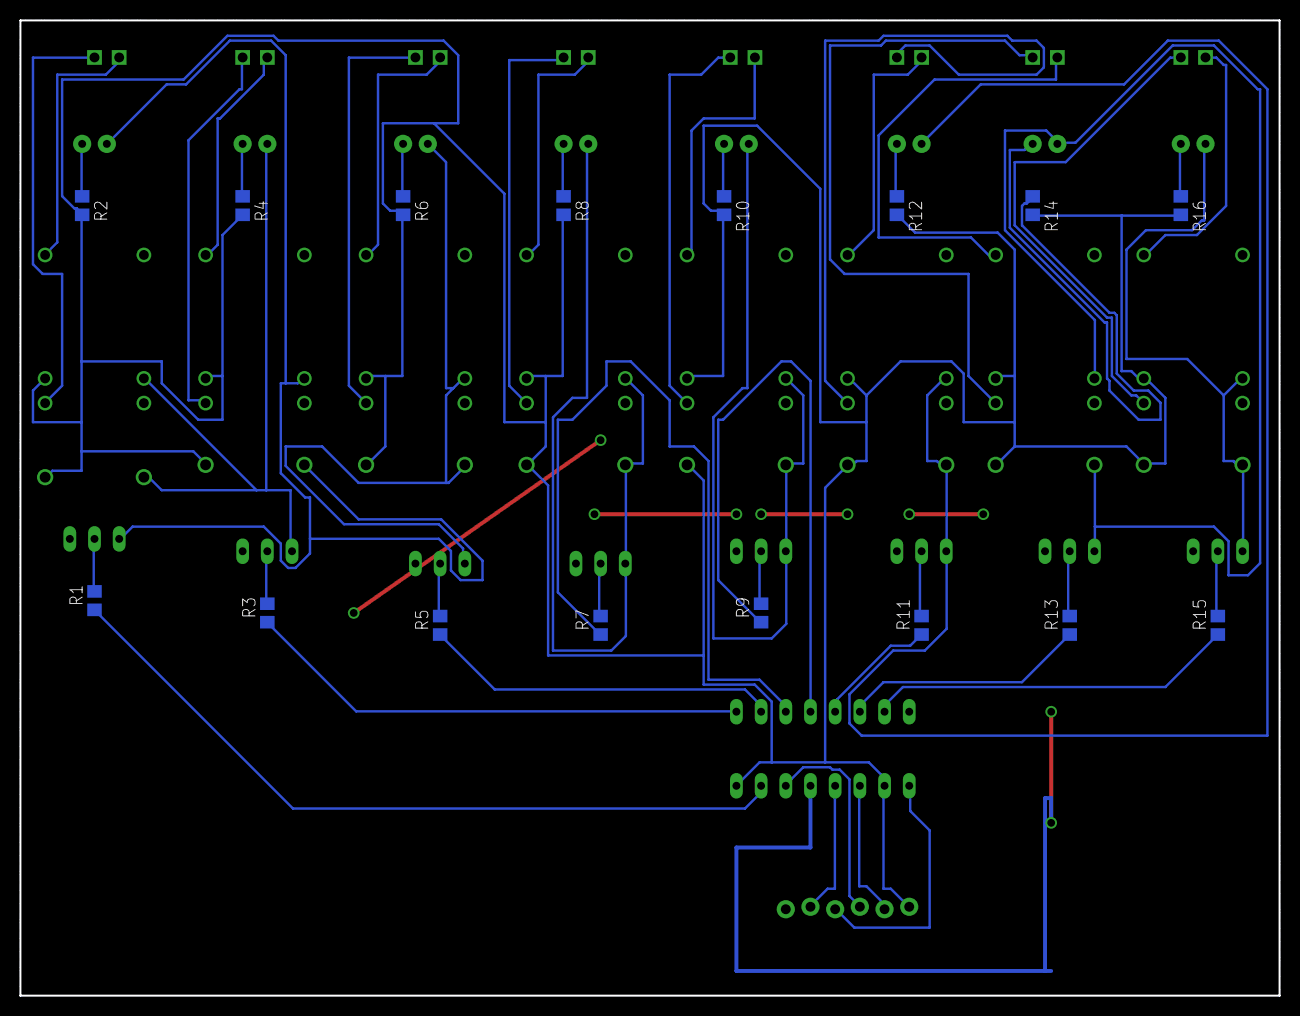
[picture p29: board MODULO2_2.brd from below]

Board: 2 copper layers, 129.5 x 100.3 mm, 58 parts (16 on the bottom side), 54 nets.

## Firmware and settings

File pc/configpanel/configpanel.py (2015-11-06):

import sys
import os
import json
from PyQt5.QtWidgets import (QApplication, QMainWindow, QAction, QTabWidget,
    QWidget, QLabel, QGridLayout, QCheckBox, QLineEdit, QDesktopWidget,
    QMessageBox, QFileDialog)
from PyQt5.QtGui import QIcon, QFont
from PyQt5.QtCore import Qt
from uploadconfigpanel import UploadConfigurationPanel
from downloadconfigpanel import DownloadConfigurationPanel
##### uso la versione nella dir. corrente, ottimizzata per windows
####sys.path.insert(0, '../../common')
from atomicwrite import AtomicWrite

# grid = [[" " for x in range(5)] for y in range(5)]
class ConfigurationPanel(QMainWindow):
    """docstring for ConfigurationPanel"""
    def __init__(self):
        super(ConfigurationPanel, self).__init__()
        self.bands = ["6m", "10m", "12m", "15m", "17m", "20m", "30m", "40m", "60m", "80m", "160m"]
        self.nrow = 16
        self.nrele = 24
        # creo le azioni che usero' in seguito
        self.initAction()
        self.initUI()

    def initUI(self):
        # imposto la grandezza del font
        self.setStyleSheet('font-size: 11pt;')
        # imposto le dimensioni della finestra
        self.setGeometry(0, 0, 1500, 600)
        # imposto il titolo della finestra
        self.setWindowTitle("AMC Configuration Panel")
        # creo il menu'
        self.initMenuBar()
        self.initToolBar()
        # creo le tab ed il loro contenuto
        self.initTab()
        # imposta il widget dato come widget centrale della finestra principale
        self.setCentralWidget(self.tab_widget)
        # sposta la finestra al centro del desktop
        self.centerOnScreen()
        # visualizzo il widget
        self.show()
        # visualizzo la scritta 'Ready' nella status bar
        self.statusBar().showMessage("Ready")

    def initAction(self):
        # TODO: sistemare il path delle icone
        # azione per uscire dall'applicazione
        self.exitAction = QAction(
            QIcon(os.path.join("icons", "exit.png")),
            "&Exit",
            self)
        self.exitAction.setShortcut("Ctrl+Q")
        self.exitAction.setStatusTip("Exit application")
        # collego l'azione exitAction all'evento self.close (gia' presente in PyQT)
        self.exitAction.triggered.connect(self.close)

        # azione per caricare la configurazione da file
        self.openAction = QAction(
            QIcon(os.path.join("icons", "open-configuration.png")),
            "&Load configuration",
            self)
        self.openAction.setShortcut("Ctrl+L")
        self.openAction.setStatusTip("Load to file")
        # collego l'azione openAction al mio evento che ho creato loadConfigurationFile
        self.openAction.triggered.connect(self.loadConfigurationFile)

        # azione per salvare la configurazione su file
        self.saveAction = QAction(
            QIcon(os.path.join("icons", "save-configuration.png")),
            "&Save configuration",
            self)
        self.saveAction.setShortcut("Ctrl+S")
        self.saveAction.setStatusTip("Save to file")
        self.saveAction.triggered.connect(self.saveConfigurationFile)

        # azione per spedire la configurazione al beaglebone
        self.uploadAction = QAction(
            QIcon(os.path.join("icons", "upload-configuration.png")),
            "&Upload configuration",
            self)
        self.uploadAction.setShortcut("Ctrl+U")
        self.uploadAction.setStatusTip("Upload to beaglebone")
        self.uploadAction.triggered.connect(self.uploadConfiguration)

        # azione per ricevere la configurazione dal beaglebone
        self.downloadAction = QAction(
            QIcon(os.path.join("icons", "download-configuration.png")),
            "&Download configuration",
            self)
        self.downloadAction.setShortcut("Ctrl+D")
        self.downloadAction.setStatusTip("Download from beaglebone")
        self.downloadAction.triggered.connect(self.downloadConfiguration)

        """
        serialAction = QAction("&Serial", self)
        serialAction.setShortcut("")
        serialAction.setStatusTip("")
        serialAction.triggered.connect()

        downloadAction = QAction("&Download", self)
        downloadAction.setShortcut("")
        downloadAction.setStatusTip("")
        downloadAction.triggered.connect()

        UploadAction = QAction("&Upload", self)
        UploadAction.setShortcut("")
        UploadAction.setStatusTip("")
        UploadAction.triggered.connect()
        """

    def initMenuBar(self):
        # creo il menu ed aggiungo i vari campi
        menubar = self.menuBar()
        filemenu = menubar.addMenu("&File")
        filemenu.addAction(self.openAction)
        filemenu.addAction(self.saveAction)
        filemenu.addSeparator()
        filemenu.addAction(self.downloadAction)
        filemenu.addAction(self.uploadAction)
        filemenu.addSeparator()
        # aggancio al menu il comando per uscire
        filemenu.addAction(self.exitAction)

        #configuration_menu = menubar.addMenu("&Configuration")
        #configuration_menu.addAction(self.saveAction)
        #configuration_menu.addSeparator()
        #configuration_menu.addAction(self.openAction)
        #connection_menu = menubar.addMenu("&Connection")

    def initToolBar(self):
        toolbar = self.addToolBar('ToolBar')
        toolbar.addAction(self.saveAction)
        toolbar.addSeparator()
        toolbar.addAction(self.openAction)
        toolbar.addSeparator()
        toolbar.addAction(self.downloadAction)
        toolbar.addSeparator()
        toolbar.addAction(self.uploadAction)

    def initTab(self):
        # creo un TabWidget che sara' il widget padre
        self.tab_widget = QTabWidget(self)
        labels_name = ["Active", "Label", "Bands"]
        tab_list = list()
        self.tablayout_list = list()
        self.checkbox_matrix = list()
        self.labels_matrix = list()
        self.radio1cb_matrix = list()
        self.radio2cb_matrix = list()
        for i in range(len(self.bands)):
            # aggiungo alla lista un oggetto QWidget discendente dal padre
            tab_list.append(QWidget(self.tab_widget))
            # per ogni nome band aggiungo una tab nella list che
            # sara' visualizzata nella finestra principale
            self.tab_widget.addTab(tab_list[i], self.bands[i])
            # aggiungo alla lista un oggetto per il layout a griglia discendente
            # dalla i-esima tab
            self.tablayout_list.append(QGridLayout(tab_list[i]))
            self.tablayout_list[i].setObjectName("tab" + str(i).zfill(2))
            #print (self.tablayout_list[i].objectName())
            # nella i-esima tab creo un layout a griglia e posiziono i vari elementi
            boldfont = QFont()
            boldfont.setBold(True)
            active_lbl = QLabel('Active:', tab_list[i])
            active_lbl.setFont(boldfont)
            label_lbl = QLabel('Label:', tab_list[i])
            label_lbl.setFont(boldfont)
            radio1_lbl = QLabel('Radio 1:', tab_list[i])
            radio1_lbl.setFont(boldfont)
            radio2_lbl = QLabel('Radio 2:', tab_list[i])
            radio2_lbl.setFont(boldfont)
            self.tablayout_list[i].addWidget(active_lbl, 0, 0)
            #self.tablayout_list[i].addWidget(QLabel("Label", tab_list[i]), 0, 1)
            self.tablayout_list[i].addWidget(label_lbl, 0, 1)
            #self.tablayout_list[i].addWidget(QLabel("Radio 1", tab_list[i]), 0, 2, 1, self.nrele)
            self.tablayout_list[i].addWidget(radio1_lbl, 0, 2, 1, self.nrele)
            #self.tablayout_list[i].addWidget(QLabel("Radio 2", tab_list[i]), 0, 26, 1, self.nrele)
            self.tablayout_list[i].addWidget(radio2_lbl, 0, 26, 1, self.nrele)
            self.checkbox_matrix.append(list())
            self.labels_matrix.append(list())
            self.radio1cb_matrix.append(list())
            self.radio2cb_matrix.append(list())
            # per ogni tab devo creare tutti i suoi oggetti al suo interno
            for y in range(self.nrow):
                self.checkbox_matrix[i].append(QCheckBox(tab_list[i]))
                self.checkbox_matrix[i][y].setObjectName("checkboxRowTab" + str(i).zfill(2))
                self.checkbox_matrix[i][y].setCheckState(Qt.Unchecked)
                self.checkbox_matrix[i][y].stateChanged.connect(self.changeStateRow)
                #self.checkbox_matrix[i][y].setSizePolicy(QSizePolicy.Expanding,QSizePolicy.Expanding)
                self.tablayout_list[i].addWidget(self.checkbox_matrix[i][y], y+1, 0)
                self.labels_matrix[i].append(QLineEdit(tab_list[i]))
                self.labels_matrix[i][y].setEnabled(False)
                self.tablayout_list[i].addWidget(self.labels_matrix[i][y], y+1, 1)
                self.radio1cb_matrix[i].append(list())
                self.radio2cb_matrix[i].append(list())
                for z in range(self.nrele):
                    self.radio1cb_matrix[i][y].append(QCheckBox(tab_list[i]))
                    #self.radio1cb_matrix[i][y][z].setSizePolicy(QSizePolicy.Expanding,QSizePolicy.Expanding)
                    #self.radio1cb_matrix[i][y][z].stateChanged.connect(self.changeCheckBoxState)
                    self.radio1cb_matrix[i][y][z].setEnabled(False)
                    # aggiungo 1 a y perche' devo contare le etichette (Active, Label, Radio1, Radio2)
                    # aggiungo 2 a z perche' devo tenere conto dei widget di sinistra (checkbox e label)
                    self.tablayout_list[i].addWidget(self.radio1cb_matrix[i][y][z], y+1, z+2)

                    self.radio2cb_matrix[i][y].append(QCheckBox(tab_list[i]))
                    #self.radio2cb_matrix[i][y][z].stateChanged.connect(self.changeCheckBoxState)
                    self.radio2cb_matrix[i][y][z].setEnabled(False)
                    # aggiungo 1 a y perche' devo contare le etichette (Active, Label, Radio1, Radio2)
                    # aggiungo 2 a z perche' devo tenere conto dei widget di sinistra (checkbox, label e 24 checkbox)
                    self.tablayout_list[i].addWidget(self.radio2cb_matrix[i][y][z], y+1, z+26)

    def centerOnScreen(self):
        '''
        Centers the window on the screen.
        '''
        # prende le dimensioni della finestra
        qr = self.frameGeometry()
        # prende il punto centrale del display date le sue dimensioni
        cp = QDesktopWidget().availableGeometry().center()
        # muoviamo la finestra al centro dello schermo
        qr.moveCenter(cp)
        self.move(qr.topLeft())

    def warningOpenFile(self):
        QMessageBox.warning(self, 'Errore', "Errore nell'apertura del file")

    def closeEvent(self, event):
        reply = QMessageBox.question(self, 'Message', "Are you sure to quit?",
                QMessageBox.Yes | QMessageBox.No, QMessageBox.No)
        if reply == QMessageBox.Yes:
            event.accept()
        else:
            event.ignore()

    def keyPressEvent(self, e):
        if e.key() == Qt.Key_Escape:
            self.close()

    def changeStateRow(self, state):
        if state == Qt.Checked or state == Qt.Unchecked:
            sender = self.sender()
            '''
            Trovare un modo migliore per trovare la posizione dell'oggetto
            che effettua la richiesta perche' questo fa schifo!!!!
            '''
            #print ("Sender: ", sender.objectName())
            # Recupero l'indice della tab dove si trova la checkbox attraverso il nome
            indexTab = int(sender.objectName()[-2:])
            #print ("indexTab: ", indexTab)
            indexPos = self.tablayout_list[indexTab].indexOf(sender)
            #print ("indexPos:", indexPos)
            location = self.tablayout_list[indexTab].getItemPosition(indexPos)
            indexRow = location[0]
            indexColumn = location[1]
            text = "Tab: " + self.bands[indexTab] + ", Row: " + str(indexColumn) + \
                    ", Column: " + str(indexRow) + ", State: " + str(state)
            #print (text)
            self.statusBar().showMessage(text)
            if state == Qt.Checked:
                self.labels_matrix[indexTab][indexRow-1].setEnabled(True)
                for i in range(self.nrele):
                    # -1 perche' e' compresa la riga delle etichette
                    self.radio1cb_matrix[indexTab][indexRow-1][i].setEnabled(True)
                    self.radio2cb_matrix[indexTab][indexRow-1][i].setEnabled(True)
            else:
                self.labels_matrix[indexTab][indexRow-1].setEnabled(False)
                for i in range(self.nrele):
                    self.radio1cb_matrix[indexTab][indexRow-1][i].setEnabled(False)
                    self.radio2cb_matrix[indexTab][indexRow-1][i].setEnabled(False)

    def changeCheckBoxState(self, state):
        '''
        Funzione che stampa a terminale tutte le volte che viene cliccata
        una checkbox
        '''
        if state == Qt.Checked or state == Qt.Unchecked:
        #if True:
            sender = self.sender()
            #self.statusBar().showMessage(sender.text())
            indexTab = self.tab_widget.currentIndex()
            """
            button = self.sender()
            idx = self.layout.indexOf(button)
            location = self.layout.getItemPosition(idx)
            print ("Button", button, "at row/col", location[:2])
            """
            idx = self.tablayout_list[indexTab].indexOf(sender)
            location = self.tablayout_list[indexTab].getItemPosition(idx)
            indexRow = location[0]
            indexColumn = location[1]
            '''
            print ("indexTab: ", indexTab)
            print ("idx:", idx)
            text = "Tab: " + str(indexTab) + ", Row: " + str(indexColumn) + \
                    ", Column: " + str(indexRow) + ", State: " + str(state)
            print (text)
            self.statusBar().showMessage(text)
            '''
            #trovo la banda
            band = self.bands[indexTab]
            presetnumber = indexRow
            if indexColumn > 1 and indexColumn < 26:
                ptype = "radioA, relay " + str(location[1]-1)
            else:
                # -25 perche' sarebbe -26 (numero oggetti) + 1 (perche' non voglio partire da 0 ma da 1)
                ptype = "radioB, relay " + str(location[1]-25) # attenzione alla "label"
            print ("Posizione decodificata: banda ", band, ", preset numero ", presetnumber, ", tipo ", ptype)

    def createJsonConfiguration(self):
        jsonconfig = '{"relayconfig":{\n'
        commaTab = False
        for indexTab in range(len(self.bands)):
            firstRow = True
            nRowChecked = 0
            for indexRow in range(self.nrow):
                if self.checkbox_matrix[indexTab][indexRow].isChecked() == True:
                    nRowChecked += 1
                    if firstRow:
                        if commaTab:
                            # inserisco una virgola per ogni tab a parte l'ultima
                            jsonconfig += ',\n'
                            commaTab = False
                        jsonconfig += '\t"' + self.bands[indexTab] + '":{\n'
                        firstRow = False
                        commaTab = True
                    else:
                        jsonconfig += ',\n'
                    jsonconfig += '\t\t"' + str(indexRow) + '":{\n\t\t\t"label":' + \
                                '"' + self.labels_matrix[indexTab][indexRow].text() + '",\n'
                    relayA = ""
                    relayB = ""
                    for z in range(self.nrele):
                        if self.radio1cb_matrix[indexTab][indexRow][z].isChecked() == True:
                            relayA += "1"
                        else:
                            relayA += "0"
                        if self.radio2cb_matrix[indexTab][indexRow][z].isChecked() == True:
                            relayB += "1"
                        else:
                            relayB += "0"
                    jsonconfig += '\t\t\t"relayA":' + '"' + relayA + '",\n\t\t\t"relayB":' + \
                                '"' + relayB + '"\n\t\t}'
            if nRowChecked > 0:
                # chiudo parentesi prima di label
                jsonconfig += '\n\t}'
        jsonconfig += '\n}}'
        return jsonconfig

    def saveConfigurationFile(self, filename):
        """
        prendo il primo elemento, cioe' 0 perche' getSaveFileName mi restituisce
        una lista del tipo (u'/home/giulio/workspace/amc/test-config.json',
        u'JSON Files (*.json)')
        """
        fname = QFileDialog.getSaveFileName(self, 'Save configuration',
                os.getcwd(), "JSON Files (*.json)")[0]
        if fname:
            #print (fname)
            ###AtomicWrite.writeFile(fname, jsonconfig)
            self.saveConf(fname)
            #print ("Scrittura eseguita correttamente su file")

    def saveConf(self, filename):
        jsonconfig = self.createJsonConfiguration()
        AtomicWrite.writeFile(filename, jsonconfig)

    def loadConfigurationFile(self):
        """
        apre una finestra di selezione in /home dove e' possibile selezionare solo file json
        prendo il primo elemento, cioe' 0 perche' getOpenFileName mi restituisce
        una lista del tipo (u'/home/giulio/workspace/amc/test-config.json',
        u'JSON Files (*.json)')
        """
        fname = QFileDialog.getOpenFileName(self, 'Load configuration',
                os.getcwd(), "JSON Files (*.json)")[0]
        if fname:
            #print (fname)
            try:
                with open(fname, 'r') as fin:
                    config = json.load(fin)
                #print (config)
                for indexTab in range(len(self.bands)):
                    for indexRow in range(self.nrow):
                        if self.checkbox_matrix[indexTab][indexRow].isChecked() == True:
                            self.checkbox_matrix[indexTab][indexRow].setCheckState(Qt.Unchecked)
                for tab in config['relayconfig']:
                    for row in config['relayconfig'][tab]:
                        #print (tab + "-" + row)
                        label = config['relayconfig'][tab][row]['label']
                        relayA = config['relayconfig'][tab][row]['relayA']
                        relayB = config['relayconfig'][tab][row]['relayB']
                        #print (label + relayA + relayB)
                        self.checkbox_matrix[self.bands.index(tab)][int(row)].setCheckState(Qt.Checked)
                        self.labels_matrix[self.bands.index(tab)][int(row)].setText(label)
                        for i in range(self.nrele):
                            if relayA[i] == '1':
                                self.radio1cb_matrix[self.bands.index(tab)][int(row)][i].setCheckState(Qt.Checked)
                            if relayB[i] == '1':
                                self.radio2cb_matrix[self.bands.index(tab)][int(row)][i].setCheckState(Qt.Checked)
            except Exception as e:
                QMessageBox.warning(self, 'Errore', str(e))

    def loadConfiguration(self, config):
        try:
            for indexTab in range(len(self.bands)):
                for indexRow in range(self.nrow):
                    if self.checkbox_matrix[indexTab][indexRow].isChecked() == True:
                        self.checkbox_matrix[indexTab][indexRow].setCheckState(Qt.Unchecked)
            for tab in config['relayconfig']:
                for row in config['relayconfig'][tab]:
                    #print (tab + "-" + row)
                    label = config['relayconfig'][tab][row]['label']
                    relayA = config['relayconfig'][tab][row]['relayA']
                    relayB = config['relayconfig'][tab][row]['relayB']
                    #print (label + relayA + relayB)
                    self.checkbox_matrix[self.bands.index(tab)][int(row)].setCheckState(Qt.Checked)
                    self.labels_matrix[self.bands.index(tab)][int(row)].setText(label)
                    for i in range(self.nrele):
                        if relayA[i] == '1':
                            self.radio1cb_matrix[self.bands.index(tab)][int(row)][i].setCheckState(Qt.Checked)
                        if relayB[i] == '1':
                            self.radio2cb_matrix[self.bands.index(tab)][int(row)][i].setCheckState(Qt.Checked)
        except Exception as e:
            QMessageBox.warning(self, 'Errore', str(e))

    def uploadConfiguration(self):
        self.saveConf("current.json")
        uploadConfiguration_panel = UploadConfigurationPanel()
        #uploadConfiguration_panel.show()
        uploadConfiguration_panel.exec_()

    def downloadConfiguration(self):
        downloadConfiguration_panel = DownloadConfigurationPanel()
        #uploadConfiguration_panel.show()
        downloadConfiguration_panel.exec_()
        config = downloadConfiguration_panel.getConfig()
        if config:
            self.loadConfiguration(config)


if __name__ == '__main__':
    # Every PyQt5 application must create an application object.
    app = QApplication(sys.argv)
    configuration_panel = ConfigurationPanel()
    #configuration_panel.show()
    # l'applicazione rimane in loop
    sys.exit(app.exec_())

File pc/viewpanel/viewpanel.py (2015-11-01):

import sys, time, os.path, queue
import serial.tools.list_ports
from com_monitor import ComMonitorThread
from livedatafeed import LiveDataFeed
from PyQt5.QtWidgets import (QApplication, QMainWindow, QAction, QHBoxLayout,
    QVBoxLayout, QGridLayout, QComboBox, QLabel, QRadioButton, QButtonGroup,
    QGroupBox, QWidget, QDesktopWidget, QMessageBox)
from PyQt5.QtGui import QIcon, QFont
from PyQt5.QtCore import Qt, QTimer

class ViewPanel(QMainWindow):
    def __init__(self):
        super(ViewPanel, self).__init__()
        # imposto la grandezza del font
        self.setStyleSheet('font-size: 10pt;')
        # all'avvio del programma e' selezionata la radio A
        self.radio = "A"
        self.portnum = ""
        self.nantenne = 8
        self.nrelay = 24
        # indica se sono in ascolto o no
        self.monitor_active = False
        # variabile per il thread di ascolto
        self.com_monitor = None
        # indica l'ultimo aggiornamento della view
        self.lastupdatedata = None
        # varibile per avere i dati piu' recenti
        self.livefeed = LiveDataFeed()
        # code per i dati e per gli errori
        self.data_q = queue.LifoQueue()
        self.error_q = queue.Queue()
        # conto alla rovescia
        self.timer = QTimer()
        self.initAction()
        # inizializzo la toolbar
        self.initToolBar()
        self.radio_groupbox_defaultStyleSheet = None
        #self.radioTX_groupbox_defaultStyleSheet = None
        self.antenne_defaultStyleSheet = None
        # creo gli elementi della finistra
        self.initLayout()
        self.initSettingsLayout()
        self.setActionsEnableState()

        ### TEST
        #self.portnum = "/dev/pts/26"
        #self.start_action.setEnabled(True)

    def initAction(self):
        # TODO: sistemare il path delle icone
        # azione per uscire dall'applicazione
        self.exit_action = QAction(
            QIcon(os.path.join("icons", "exit.png")),
            "&Exit",
            self)
        self.exit_action.setShortcut("Ctrl+Q")
        self.exit_action.setStatusTip("Exit application")
        # collego l'azione exit_action all'evento self.close (gia' presete in PyQT)
        self.exit_action.triggered.connect(self.close)

        self.start_action = QAction(
            QIcon(os.path.join("icons", "start.png")),
            "&Start",
            self)
        self.start_action.setShortcut("Ctrl+S")
        self.start_action.setStatusTip("Start listening")
        self.start_action.triggered.connect(self.startListening)

        self.stop_action = QAction(
            QIcon(os.path.join("icons", "stop.png")),
            "&Stop",
            self)
        self.stop_action.setShortcut("Ctrl+B")
        self.stop_action.setStatusTip("Stop listening")
        self.stop_action.triggered.connect(self.stopListening)

    def initToolBar(self):
        toolbar = self.addToolBar('ToolBar')
        toolbar.addAction(self.start_action)
        toolbar.addSeparator()
        toolbar.addAction(self.stop_action)

    def initSettingsLayout(self):
         # imposto il titolo della finestra
        self.setWindowTitle("RadioA")
        #self.setGeometry(0, 0, 600, 600)
        # sposta la finestra al centro del desktop
        self.centerOnScreen()
        # visualizzo la scritta 'Ready' nella status bar
        self.statusBar().showMessage("Ready")
        # impongo che la finestra sia sempre in primo piano
        self.setWindowFlags(Qt.WindowStaysOnTopHint)

    def initLayout(self):
        boldfont = QFont()
        boldfont.setBold(True)
        settings_layout = QHBoxLayout()
        settings_layout.addStretch(2)
        com_lbl = QLabel('COM Port:')
        com_lbl.setFont(boldfont)
        settings_layout.addWidget(com_lbl)
        com_c = QComboBox(self)
        self.com_list = list(serial.tools.list_ports.comports())
        # imposto la porta selezionata con il primo elemento della lista
        self.portnum = self.com_list[0][0]
        for ser in self.com_list:
            com_c.addItem(ser[1])
        com_c.activated.connect(self.selectCom)
        settings_layout.addWidget(com_c)
        settings_layout.addStretch(1)
        radio_lbl = QLabel('Radio:')
        radio_lbl.setFont(boldfont)
        settings_layout.addWidget(radio_lbl)
        radioA = QRadioButton("A")
        radioA.setChecked(True)
        radioB = QRadioButton("B")
        self.radio_group = QButtonGroup()
        self.radio_group.addButton(radioA, 0)
        self.radio_group.addButton(radioB, 1)
        self.radio_group.buttonClicked.connect(self.selectRadio)
        settings_layout.addWidget(radioA)
        settings_layout.addWidget(radioB)

        antenneRX_lbl = QLabel('Antenne:')
        self.antenne_defaultStyleSheet = antenneRX_lbl.styleSheet()
        antenneRX_lbl.setFont(boldfont)
        presetRX_lbl = QLabel('Preset:')
        presetRX_lbl.setFont(boldfont)
        self.antenneRX_list = list()
        radioRX_layout = QGridLayout()
        radioRX_layout.addWidget(antenneRX_lbl, 0, 0)
        for i in range(self.nantenne):
            self.antenneRX_list.append(QLabel(str(i+1)))
            radioRX_layout.addWidget(self.antenneRX_list[i], 0, i+1)
        radioRX_layout.addWidget(presetRX_lbl, 1, 0)
        self.presetRX_label = QLabel()
        #self.presetRX_label.setText("################")
        radioRX_layout.addWidget(self.presetRX_label, 1, 1, 1, self.nantenne)
        self.radioRX_groupbox = QGroupBox('RX')
        self.radioRX_groupbox.setLayout(radioRX_layout)
        #self.radioRX_groupbox.setStyleSheet("background-color: white;")
        self.radio_groupbox_defaultStyleSheet = self.radioRX_groupbox.styleSheet()

        antenneTX_lbl = QLabel('Antenne:')
        antenneTX_lbl.setFont(boldfont)
        presetTX_lbl = QLabel('Preset:')
        presetTX_lbl.setFont(boldfont)
        self.antenneTX_list = list()
        radioTX_layout = QGridLayout()
        radioTX_layout.addWidget(antenneTX_lbl, 0, 0)
        for i in range(self.nantenne):
            # +9 perche' l'indice visualizzato parte 9 e non da 0
            self.antenneTX_list.append(QLabel(str(i+9)))
            radioTX_layout.addWidget(self.antenneTX_list[i], 0, i+1)
        radioTX_layout.addWidget(presetTX_lbl, 1, 0)
        self.presetTX_label = QLabel()
        radioTX_layout.addWidget(self.presetTX_label, 1, 1, 1, self.nantenne)
        self.radioTX_groupbox = QGroupBox('TX')
        self.radioTX_groupbox.setLayout(radioTX_layout)
        #self.radio_groupbox_defaultStyleSheet = self.radioTX_groupbox.styleSheet()
        #self.radioTX_groupbox.setStyleSheet("QGroupBox { border: black; }")

        central_layout = QHBoxLayout()
        central_layout.addWidget(self.radioRX_groupbox)
        central_layout.addWidget(self.radioTX_groupbox)
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

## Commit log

2015-04-14 pin settings
2015-04-20 configuration sample
2015-04-22 aggiunti led sul frontale
2015-04-22 relay output
2015-04-24 relay visual output improved
2015-04-27 relay fix
2015-04-29 keyboard as radio button, atomic front, cape
2015-05-07 Schema di base
    [amc.sch]
2015-05-07 Collegato alla 5V
    [amc.sch]
2015-05-18 display driver working
2015-05-24 ricarico il file dxlog-band.py che nelle precedente commit ho cancellato
2015-05-26 aggiunta di commenti al file configuration-panel.py
2015-05-28 Schematico Logico
    [$amc.sch, amc.sch]
2015-06-01 Revert "Merge branch 'master' of https://github.com/reiser4/amc"
    This reverts commit 2380cc5f35dc9174c4fa96b8073f98d69a9940f7, reversing
    changes made to 8732c452cd3d8e44b63f819e5c39efa00f12953a.
    [display.py, dxlog-band.py, main.py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]
2015-06-01 Revert "Revert "Merge branch 'master' of https://github.com/reiser4/amc""
    This reverts commit 9bf984cd97639c6bb09fb1a1b6d99ebaa172ac6a.
    [display.py, dxlog-band.py, main.py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]
2015-06-01 Working on printing text on display
2015-06-28 rinomino i file per seguire le linee guida di PEP8
2015-07-15 adesso possiamo decidere il nome del file da salvare
2015-07-29 Eagle File
    Schematics made in Eagle
    [$amc.sch, MODULO0.brd, MODULO0.sch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]
2015-07-29 GND to MODULO0
    Ho messo a massa il Modulo0
    [MODULO0.brd, MODULO0.sch]
2015-07-29 Modulo 0 pdf
    Modulo 0 senza contorno ai fori
    [MODULO0.brd, MODULO1.brd, MODULO1.sch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]
2015-07-29 Fix Modulo 0
    Pin all'esterno della scheda
    [MODULO0.brd, MODULO2_1.brd, MODULO2_1.sch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]
2015-07-30 Modulo 2_2 pdf
    [MODULO2_1.brd]
2015-07-30 Modulo 2_1
    Modolo2_1.pdf per controllare i footprint
    [MODULO1.brd, MODULO2_1.brd, MODULO2_2.brd]
2015-07-30 PDF Vari
    Ecco Tutti i pdf
    [MODULO1.brd, MODULO2_def.brd, MODULO2_def.sch]
2015-07-31 Fix PDF
    Ho tolto alcuni layer inutili dal pdf dei PCB
    [MODULO2_def.brd]
2015-08-07 aggiunta la possibilità di fare l'upload della configurazione sul beaglebone in configpanel.py
2015-09-03 Divisione di modulo 2
    [MODULO2_pp.brd, MODULO2_pp.sch, MODULO2_ps.brd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]
2015-09-04 pdf MODULO2
    [MODULO2_ps.brd]
2015-10-15 Modulo ShiftRegister
    Aggiunto il modulo ShiftRegister, scritto con pseudocodice.
    [MODULO2_ps.brd]
2015-10-26 riorganizzazione file
    [MODULO1.kicad_pcb, MODULO1.sch, MODULO2.kicad_pcb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]
2015-10-26 relay now working
2015-10-26 relay complete
2015-10-26 relay is now foolproof
2015-10-29 display driver in C
2015-11-01 corretti alcuni errori del viewpanel
    [com_monitor.py, viewpanel.py]
2015-11-01 corretti alcuni errori nel configpanel
    [configpanel.py, viewpanel.py]
2015-11-06 aggiunta possibilità di download e upload configurazione nel configpanel
2015-11-06 current conf. upload almost working
2016-06-21 prima di reindent
2016-08-15 relay ok!!!!!
2017-08-07 letta banda da piedini giusti; scrittura display su file; fix tastiere
    [band-radio.py, band.py, display.py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]

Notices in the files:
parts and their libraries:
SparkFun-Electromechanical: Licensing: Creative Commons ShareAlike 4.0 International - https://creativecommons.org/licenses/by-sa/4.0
